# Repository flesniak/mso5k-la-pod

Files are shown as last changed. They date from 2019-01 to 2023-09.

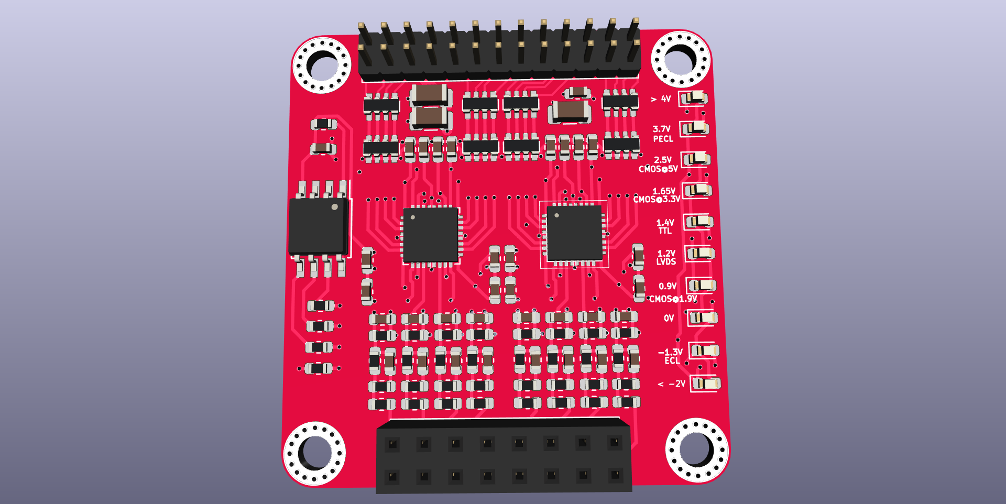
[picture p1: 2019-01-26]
img/lmh7324-8ch-3d.png

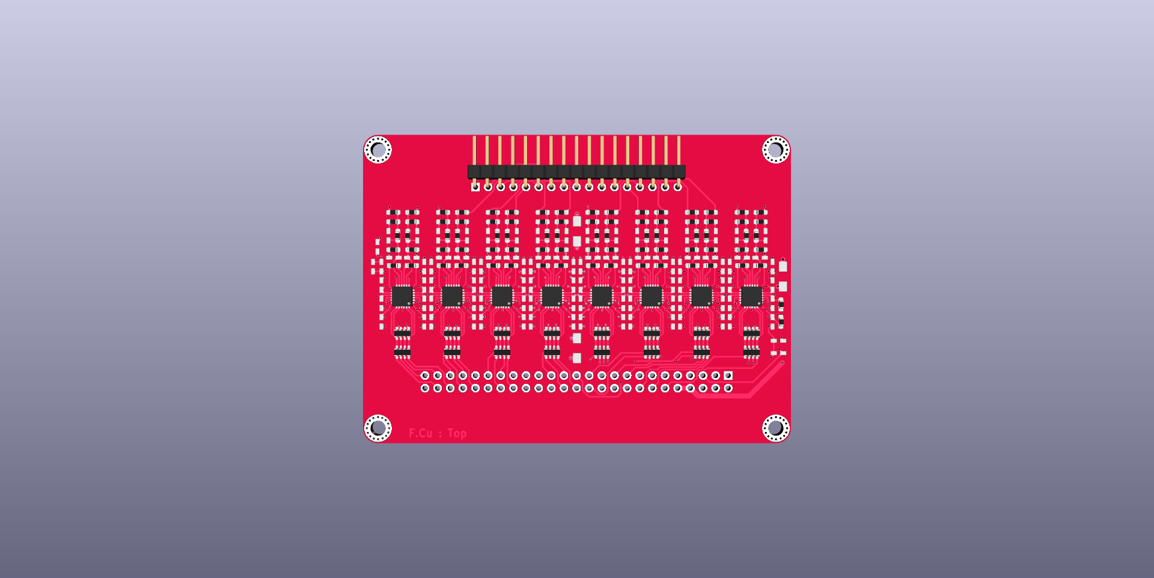
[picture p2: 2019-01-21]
img/pcb-complete-one-sided-4layer-lmh7322.png

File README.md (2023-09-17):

Original version by Flemming Frandsen: https://gitlab.com/dren.dk/mso5k-la-pod

```
MMMMMMMM               MMMMMMMM   SSSSSSSSSSSSSSS      OOOOOOOOO     555555555555555555 kkkkkkkk                            LLLLLLLLLLL                            AAA
M:::::::M             M:::::::M SS:::::::::::::::S   OO:::::::::OO   5::::::::::::::::5 k::::::k                            L:::::::::L                           A:::A
M::::::::M           M::::::::MS:::::SSSSSS::::::S OO:::::::::::::OO 5::::::::::::::::5 k::::::k                            L:::::::::L                          A:::::A
M:::::::::M         M:::::::::MS:::::S     SSSSSSSO:::::::OOO:::::::O5:::::555555555555 k::::::k                            LL:::::::LL                         A:::::::A
M::::::::::M       M::::::::::MS:::::S            O::::::O   O::::::O5:::::5             k:::::k    kkkkkkk                   L:::::L                          A:::::::::A
M:::::::::::M     M:::::::::::MS:::::S            O:::::O     O:::::O5:::::5             k:::::k   k:::::k                    L:::::L                         A:::::A:::::A
M:::::::M::::M   M::::M:::::::M S::::SSSS         O:::::O     O:::::O5:::::5555555555    k:::::k  k:::::k                     L:::::L                        A:::::A A:::::A
M::::::M M::::M M::::M M::::::M  SS::::::SSSSS    O:::::O     O:::::O5:::::::::::::::5   k:::::k k:::::k    ---------------   L:::::L                       A:::::A   A:::::A
M::::::M  M::::M::::M  M::::::M    SSS::::::::SS  O:::::O     O:::::O555555555555:::::5  k::::::k:::::k     -:::::::::::::-   L:::::L                      A:::::A     A:::::A
M::::::M   M:::::::M   M::::::M       SSSSSS::::S O:::::O     O:::::O            5:::::5 k:::::::::::k      ---------------   L:::::L                     A:::::AAAAAAAAA:::::A
M::::::M    M:::::M    M::::::M            S:::::SO:::::O     O:::::O            5:::::5 k:::::::::::k                        L:::::L                    A:::::::::::::::::::::A
M::::::M     MMMMM     M::::::M            S:::::SO::::::O   O::::::O5555555     5:::::5 k::::::k:::::k                       L:::::L         LLLLLL    A:::::AAAAAAAAAAAAA:::::A
M::::::M               M::::::MSSSSSSS     S:::::SO:::::::OOO:::::::O5::::::55555::::::5k::::::k k:::::k                    LL:::::::LLLLLLLLL:::::L   A:::::A             A:::::A
M::::::M               M::::::MS::::::SSSSSS:::::S OO:::::::::::::OO  55:::::::::::::55 k::::::k  k:::::k                   L::::::::::::::::::::::L  A:::::A               A:::::A
M::::::M               M::::::MS:::::::::::::::SS    OO:::::::::OO      55:::::::::55   k::::::k   k:::::k                  L::::::::::::::::::::::L A:::::A                 A:::::A
MMMMMMMM               MMMMMMMM SSSSSSSSSSSSSSS        OOOOOOOOO          555555555     kkkkkkkk    kkkkkkk                 LLLLLLLLLLLLLLLLLLLLLLLLAAAAAAA                   AAAAAAA
```

This is a reimplementation of the Logic Analyzer pod for the Rigol MSO5000 scopes.

The scopes all come with the ability to accept a logic analyzer, all that's needed is a probe, this project is the implementation of the probe.

The schematic and PCB is in kicad 5 format.

# Sub-projects

There are a number of different projects each in its own subdir:

## lmh7324-16ch

* All 16 channels on a single board
* Uses 4x LMH7324 comparators
* Shows threshold voltage of each 8ch bank

## lmh7324-8ch

* 8 channel frontend pod
* On a 4 layer board
* With lmh7324 comparators
* And a simple volt-meter that shows the threshold voltage.

## breakout
* Board for converting the 2x25 2.54 mm pitch connector on the scope to two 2x13 pin 1.27 mm pitch connectors.

## panel-2019-03-20

* Panel produced in march.

## voltmeter

The firmware for the micro controller

# Unfinished experiments

## lmh7322
* 16 channel frontend pod
* Pretty close clone of the original
* One-sided load
* On a 4 layer board
* Direct 2x50 2.54mm ribbon connector to the scope
* Status: Done, except for silkscreen

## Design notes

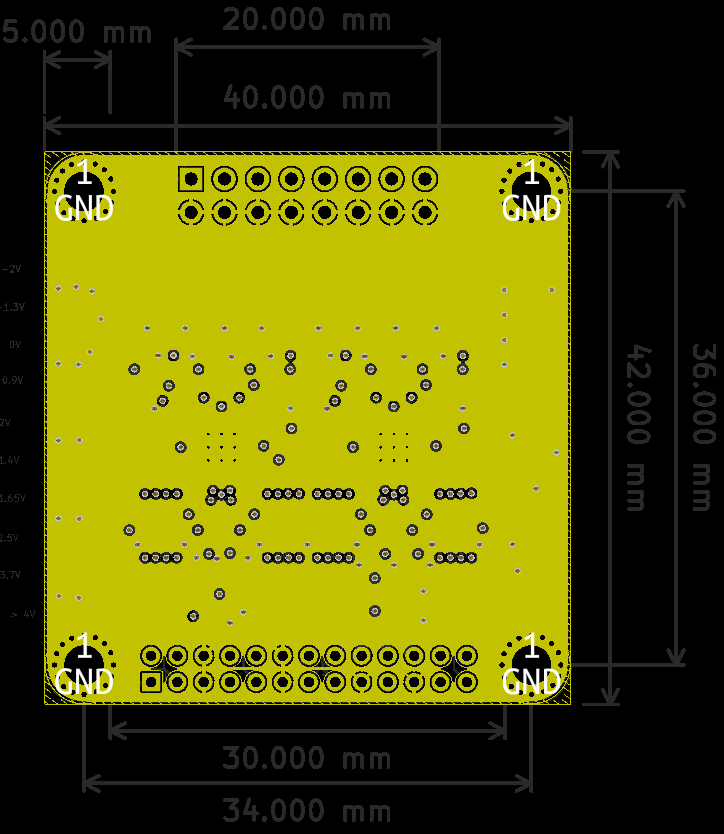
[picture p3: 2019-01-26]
img/lmh7324-8ch-8ch-layer-2-gnd.png

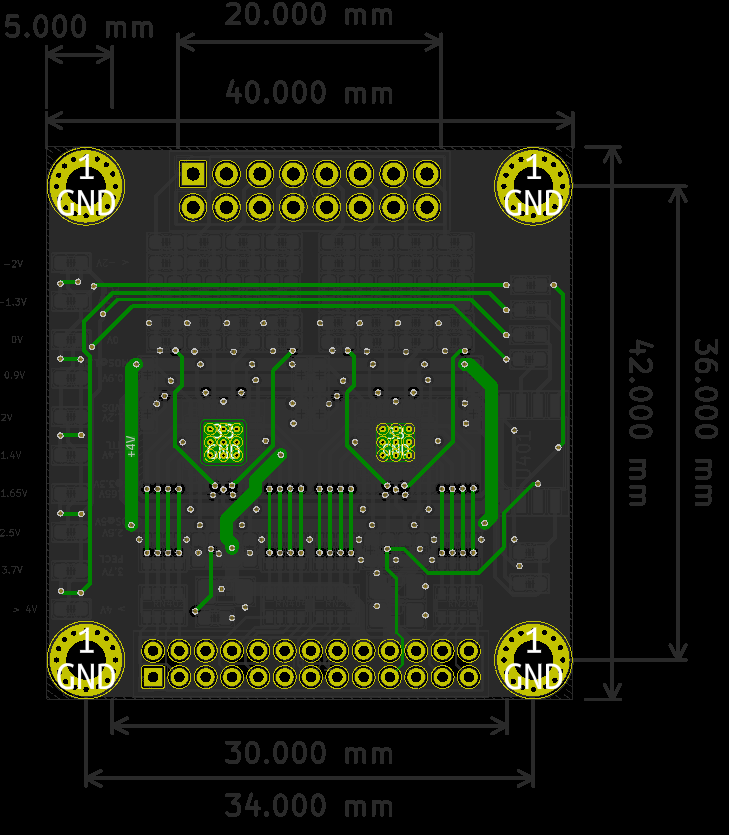
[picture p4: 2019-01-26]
img/lmh7324-8ch-8ch-bottom.png

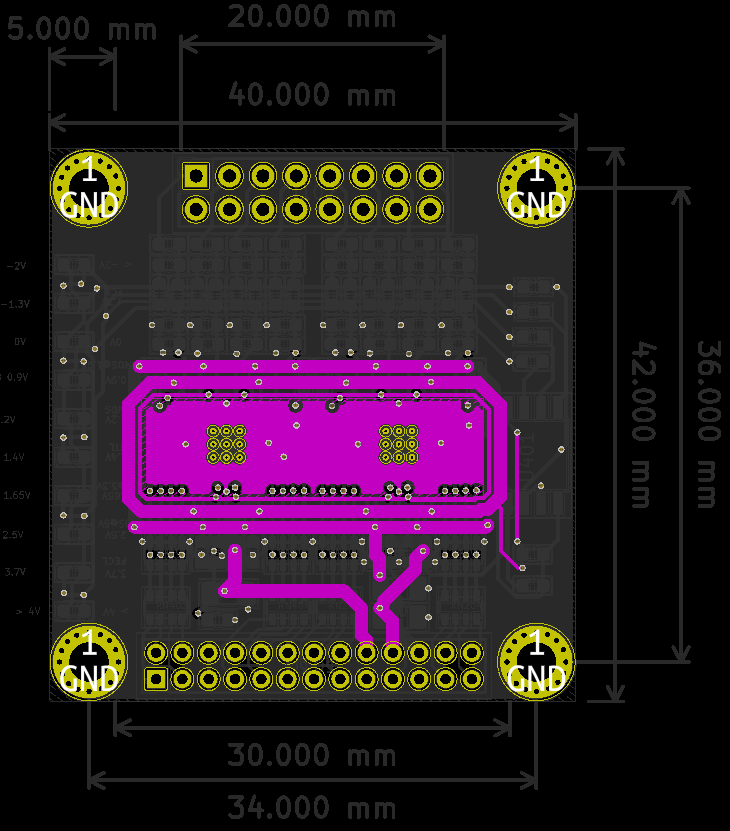
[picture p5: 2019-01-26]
img/lmh7324-8ch-8ch-layer-3-power.png

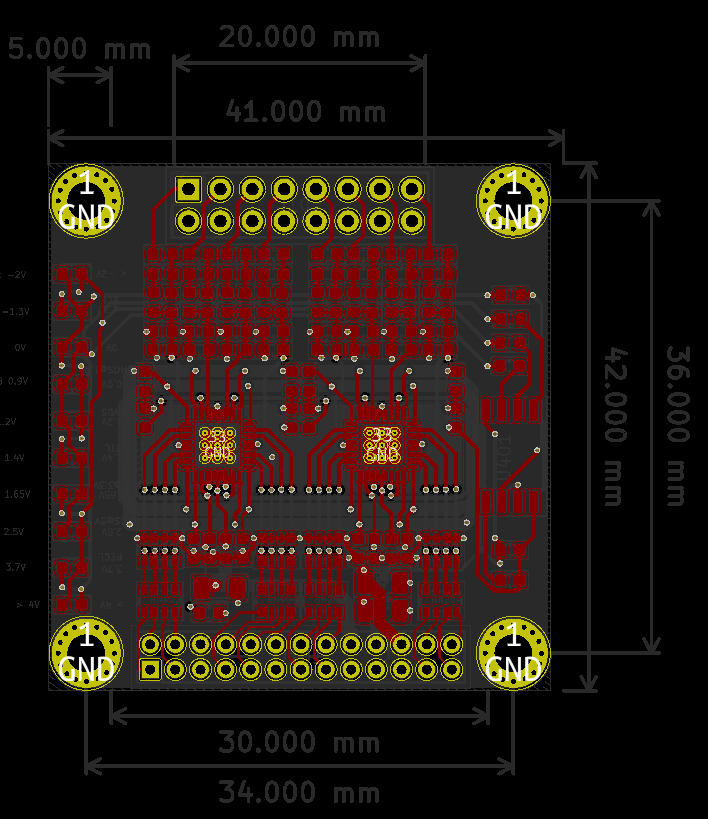
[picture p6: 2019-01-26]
img/lmh7324-8ch-8ch-top.png

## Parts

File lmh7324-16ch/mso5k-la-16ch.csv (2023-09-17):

Source: | /home/fabian/repositories/elektronik/mso5k-la-pod/lmh7324-16ch/mso5k-la-16ch.kicad_sch
Date: | Mo 22 Mai 2023 22:08:21 CEST
Tool: | Eeschema (6.0.11)
Generator: | /usr/share/kicad/plugins/bom_csv_grouped_by_value_with_fp.py
Component Count: | 237
Ref | Qnty | Value | Cmp name | Footprint | Description | Vendor
C1, C2, C3, | 3 | 10uF | C | Capacitor_SMD:C_0805_2012Metric | Unpolarized capacitor
C4, C22, C23, C25, C26, C27, C28, C50, C51, C53, C54, C55, C56, C61, C62, C80, C81, C83, C84, C85, C86, C108, C109, C111, C112, C113, C114, | 27 | 100n | C | Capacitor_SMD:C_0603_1608Metric | Unpolarized capacitor
C5, C6, C7, C8, C9, C10, C11, C12, C15, C18, C21, C24, C33, C34, C35, C36, C37, C38, C39, C40, C43, C46, C49, C52, C63, C64, C65, C66, C67, C68, C69, C70, C71, C74, C75, C76, C91, C92, C93, C94, C95, C96, C97, C98, C99, C102, C103, C104, | 48 | 10n | C | Capacitor_SMD:C_0402_1005Metric | Unpolarized capacitor
C13, C14, C29, C30, C41, C42, C57, C58, C72, C73, C87, C88, C100, C101, C115, C116, | 16 | 3.3p | C | Capacitor_SMD:C_0603_1608Metric | Unpolarized capacitor
C16, C17, C31, C32, C44, C45, C59, C60, C77, C78, C89, C90, C105, C106, C117, C118, | 16 | 27p | C | Capacitor_SMD:C_0603_1608Metric | Unpolarized capacitor
C19, C20, C47, C48, C79, C82, C107, C110, | 8 | 10n | C | Capacitor_SMD:C_0603_1608Metric | Unpolarized capacitor
D1, D11, | 2 | > 4V | LED | LED_SMD:LED_0603_1608Metric | Light emitting diode
D2, D12, | 2 | PECL 3.7V | LED | LED_SMD:LED_0603_1608Metric | Light emitting diode
D3, D13, | 2 | CMOS 5 2.5V | LED | LED_SMD:LED_0603_1608Metric | Light emitting diode
D4, D14, | 2 | CMOS 3.3 1.65V | LED | LED_SMD:LED_0603_1608Metric | Light emitting diode
D5, D15, | 2 | TTL 1.4V | LED | LED_SMD:LED_0603_1608Metric | Light emitting diode
D6, D16, | 2 | LVDS 1.2V | LED | LED_SMD:LED_0603_1608Metric | Light emitting diode
D7, D17, | 2 | CMOS 1.8 0.9V | LED | LED_SMD:LED_0603_1608Metric | Light emitting diode
D8, D18, | 2 | 0V | LED | LED_SMD:LED_0603_1608Metric | Light emitting diode
D9, D19, | 2 | ECL -1.3V | LED | LED_SMD:LED_0603_1608Metric | Light emitting diode
D10, D20, | 2 | < -2V | LED | LED_SMD:LED_0603_1608Metric | Light emitting diode
H1, H2, H3, H4, | 4 | MountingHole_Pad | MountingHole_Pad | MountingHole:MountingHole_3.2mm_M3_Pad_Via | Mounting Hole with connection
J1, | 1 | scope | Conn_02x25_Odd_Even | Connector_IDC:IDC-Header_2x25_P2.54mm_Vertical | Generic connector, double row, 02x25, odd/even pin numbering scheme (row 1 odd numbers, row 2 even numbers), script generated (kicad-library-utils/schlib/autogen/connector/)
J2, J7, | 2 | in | Conn_02x08_Odd_Even | Connector_PinSocket_2.54mm:PinSocket_2x08_P2.54mm_Vertical | Generic connector, double row, 02x08, odd/even pin numbering scheme (row 1 odd numbers, row 2 even numbers), script generated (kicad-library-utils/schlib/autogen/connector/)
J8, | 1 | Conn_02x03_Odd_Even | Conn_02x03_Odd_Even | Connector_PinSocket_2.54mm:PinSocket_2x03_P2.54mm_Vertical | Generic connector, double row, 02x03, odd/even pin numbering scheme (row 1 odd numbers, row 2 even numbers), script generated (kicad-library-utils/schlib/autogen/connector/)
J9, | 1 | Conn_01x04_Female | Conn_01x04_Female | Connector_PinHeader_2.54mm:PinHeader_1x04_P2.54mm_Vertical | Generic connector, single row, 01x04, script generated (kicad-library-utils/schlib/autogen/connector/)
R1, R2, R9, R10, R17, R18, R25, R26, R38, R39, R46, R47, R54, R55, R62, R63, | 16 | 300 | R | Resistor_SMD:R_0603_1608Metric | Resistor
R3, R4, R11, R12, R19, R20, R27, R28, R40, R41, R48, R49, R56, R57, R64, R65, | 16 | 497 | R | Resistor_SMD:R_0603_1608Metric | Resistor
R5, R6, R13, R14, R21, R22, R29, R30, R42, R43, R50, R51, R58, R59, R66, R67, | 16 | 90k8 | R | Resistor_SMD:R_0603_1608Metric | Resistor
R7, R8, R15, R16, R23, R24, R31, R32, R44, R45, R52, R53, R60, R61, R68, R69, | 16 | 10k | R | Resistor_SMD:R_0603_1608Metric | Resistor
R33, R34, R35, R36, R37, | 5 | 220 | R | Resistor_SMD:R_0603_1608Metric | Resistor
RN1, RN3, RN5, RN7, RN9, RN11, RN13, RN15, | 8 | 200 | R_Pack04 | Resistor_SMD:R_Array_Convex_4x0603 | 4 resistor network, parallel topology
RN2, RN4, RN6, RN8, RN10, RN12, RN14, RN16, | 8 | 49R9 | R_Pack04 | Resistor_SMD:R_Array_Convex_4x0603 | 4 resistor network, parallel topology
U1, | 1 | ATtiny44A-SS | ATtiny44A-SS | Package_SO:SOIC-14_3.9x8.7mm_P1.27mm | 20MHz, 4kB Flash, 256B SRAM, 256B EEPROM, debugWIRE, SOIC-14
U2, U3, U4, U5, | 4 | LMH7324 | LMH7324 | Package_DFN_QFN:WQFN-32-1EP_5x5mm_P0.5mm_EP3.1x3.1mm | Quad 700 ps High Speed Comparator with RSPECL Outputs, WQFN-32

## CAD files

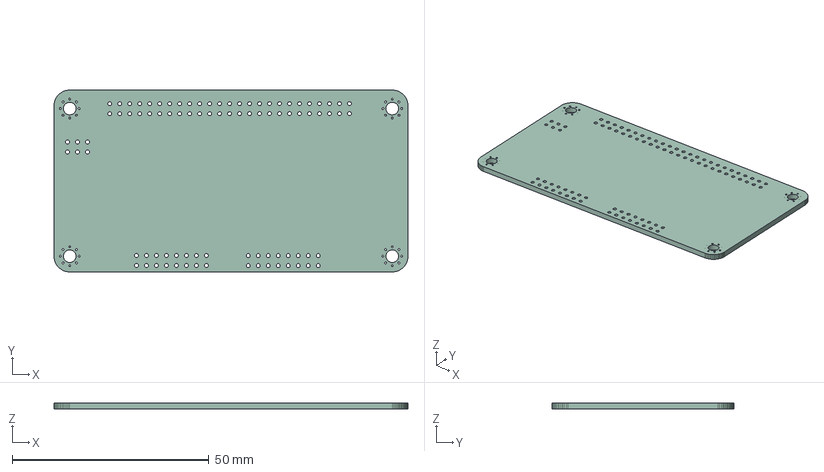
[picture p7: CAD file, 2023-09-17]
lmh7324-16ch/mso5k-la-16ch.step
90.0 x 46.2 x 1.58 mm

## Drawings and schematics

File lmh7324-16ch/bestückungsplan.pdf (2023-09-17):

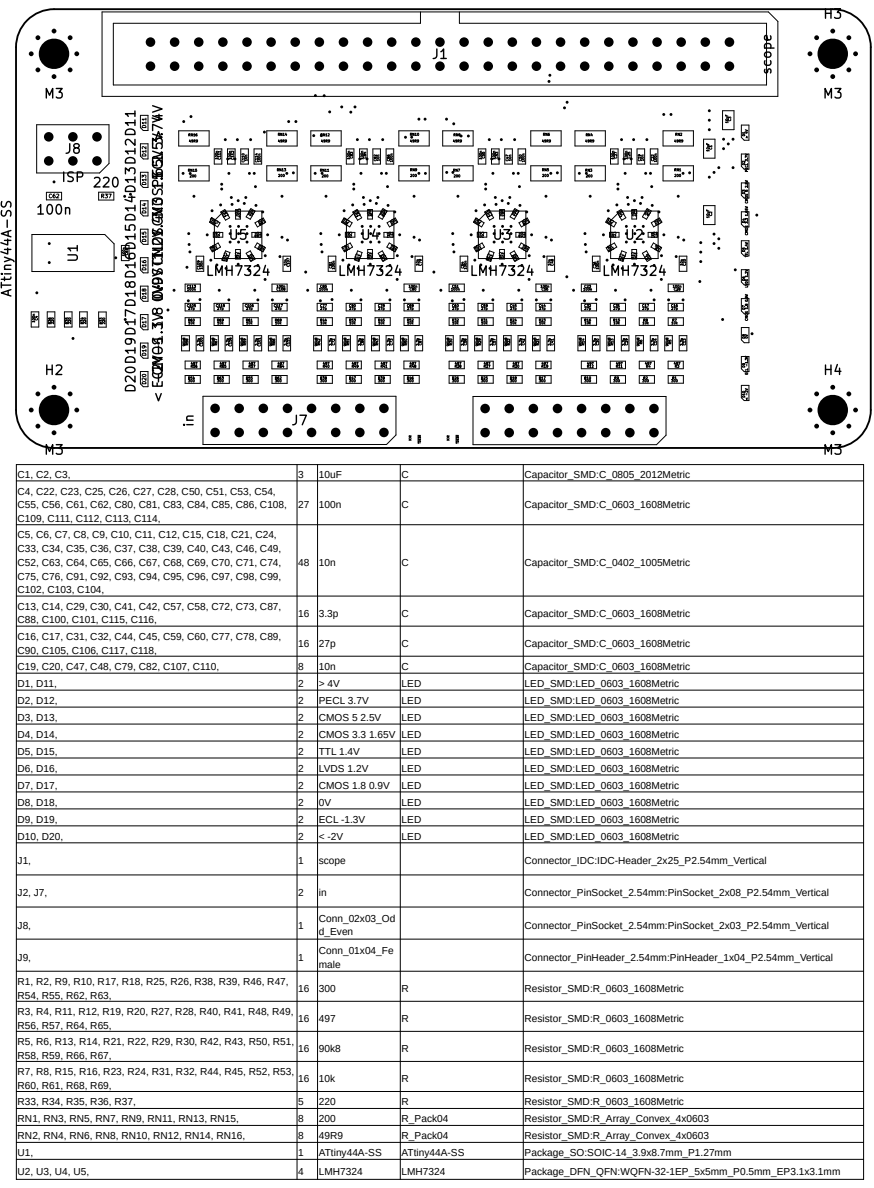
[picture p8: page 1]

C1, C2, C3, | 3 | 10uF | C | Capacitor_SMD:C_0805_2012Metric
C4, C22, C23, C25, C26, C27, C28, C50, C51, C53, C54, C55, C56, C61, C62, C80, C81, C83, C84, C85, C86, C108, C109, C111, C112, C113, C114, | 27 | 100n | C | Capacitor_SMD:C_0603_1608Metric

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

C19, C20, C47, C48, C79, C82, C107, C110, | 8 | 10n | C | Capacitor_SMD:C_0603_1608Metric
D1, D11, | 2 | > 4V | LED | LED_SMD:LED_0603_1608Metric
D2, D12, | 2 | PECL 3.7V | LED | LED_SMD:LED_0603_1608Metric
D3, D13, | 2 | CMOS 5 2.5V | LED | LED_SMD:LED_0603_1608Metric
D4, D14, | 2 | CMOS 3.3 1.65V | LED | LED_SMD:LED_0603_1608Metric
D5, D15, | 2 | TTL 1.4V | LED | LED_SMD:LED_0603_1608Metric
D6, D16, | 2 | LVDS 1.2V | LED | LED_SMD:LED_0603_1608Metric
D7, D17, | 2 | CMOS 1.8 0.9V | LED | LED_SMD:LED_0603_1608Metric
D8, D18, | 2 | 0V | LED | LED_SMD:LED_0603_1608Metric
D9, D19, | 2 | ECL -1.3V | LED | LED_SMD:LED_0603_1608Metric
D10, D20, | 2 | < -2V | LED | LED_SMD:LED_0603_1608Metric

J1, | 1 | scope | | Connector_IDC:IDC-Header_2x25_P2.54mm_Vertical

J2, J7, | 2 | in | | Connector_PinSocket_2.54mm:PinSocket_2x08_P2.54mm_Vertical

J8, | 1 | Conn_02x03_Od d_Even | | Connector_PinSocket_2.54mm:PinSocket_2x03_P2.54mm_Vertical

J9, | 1 | Conn_01x04_Fe male | | Connector_PinHeader_2.54mm:PinHeader_1x04_P2.54mm_Vertical

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

R33, R34, R35, R36, R37, | 5 | 220 | R | Resistor_SMD:R_0603_1608Metric
RN1, RN3, RN5, RN7, RN9, RN11, RN13, RN15, | 8 | 200 | R_Pack04 | Resistor_SMD:R_Array_Convex_4x0603
RN2, RN4, RN6, RN8, RN10, RN12, RN14, RN16, | 8 | 49R9 | R_Pack04 | Resistor_SMD:R_Array_Convex_4x0603
U1, | 1 | ATtiny44A-SS | ATtiny44A-SS | Package_SO:SOIC-14_3.9x8.7mm_P1.27mm
U2, U3, U4, U5, | 4 | LMH7324 | LMH7324 | Package_DFN_QFN:WQFN-32-1EP_5x5mm_P0.5mm_EP3.1x3.1mm

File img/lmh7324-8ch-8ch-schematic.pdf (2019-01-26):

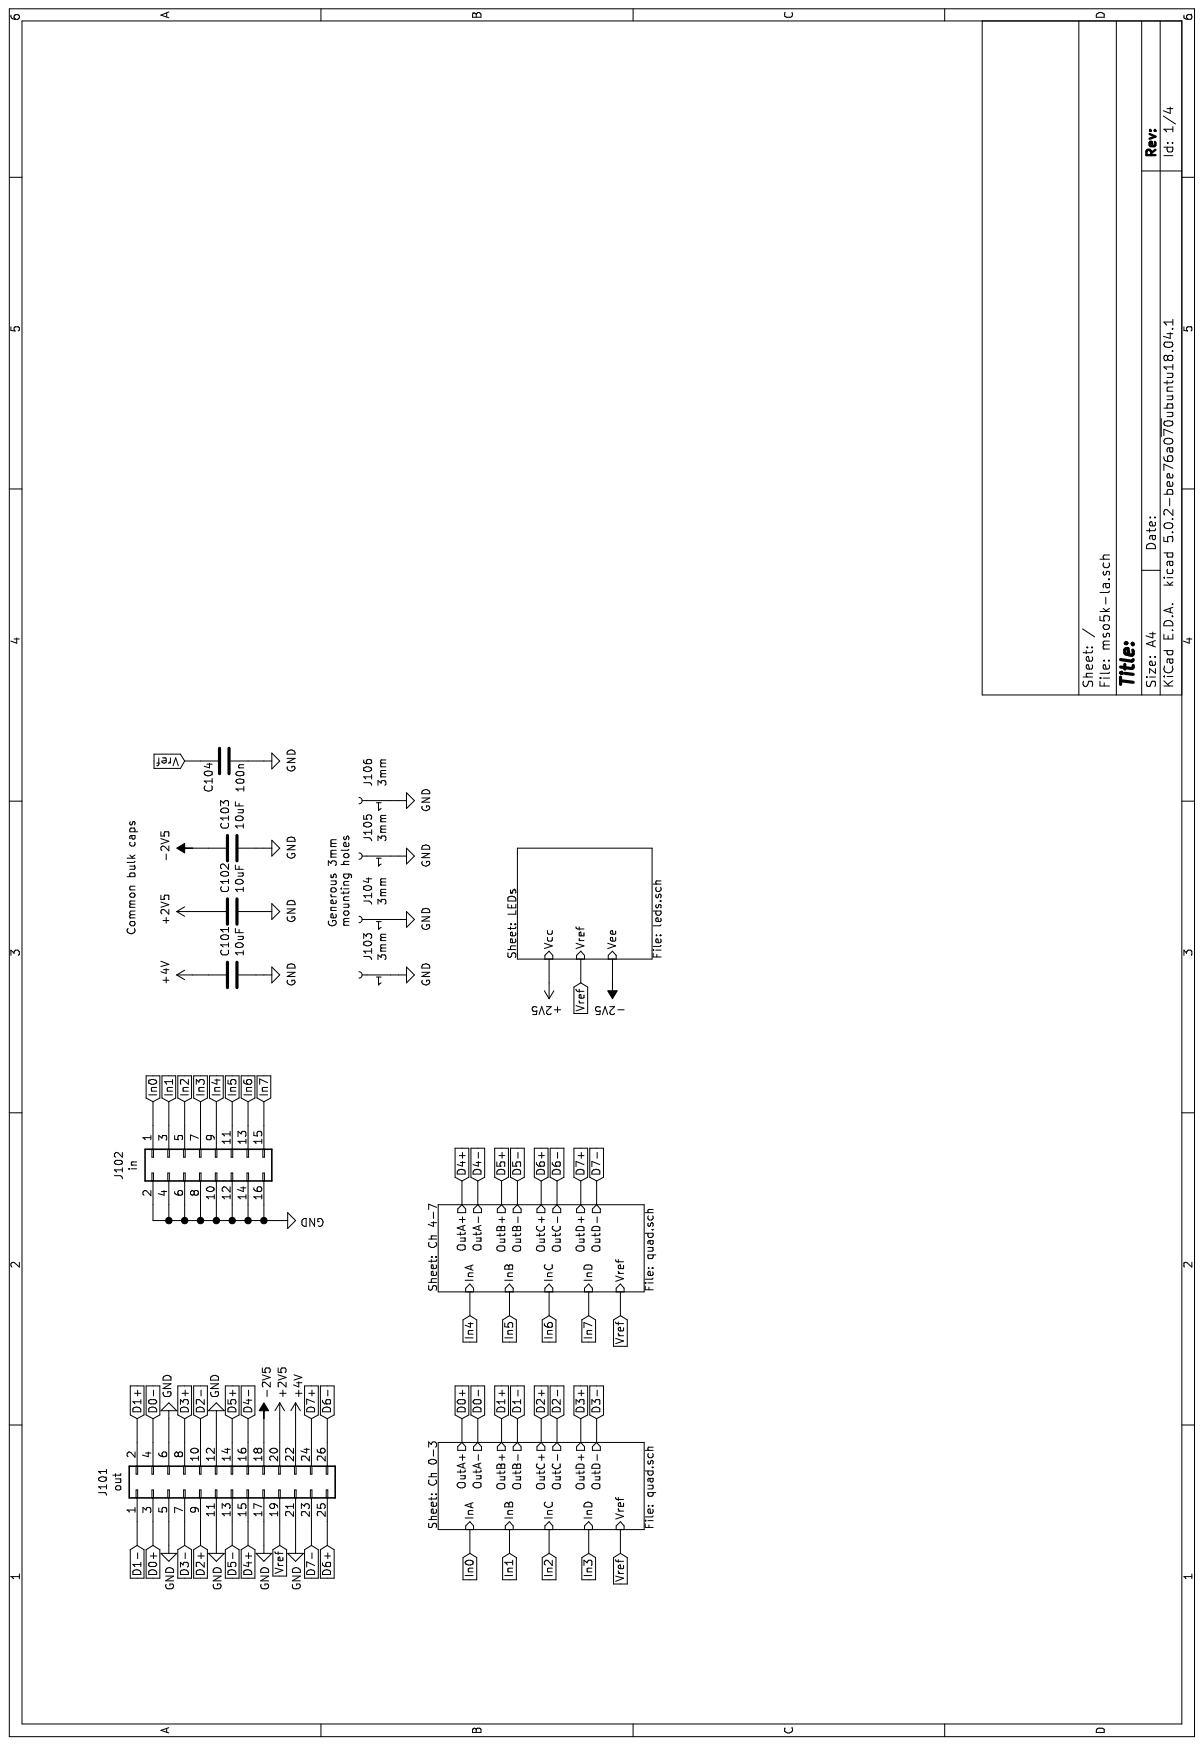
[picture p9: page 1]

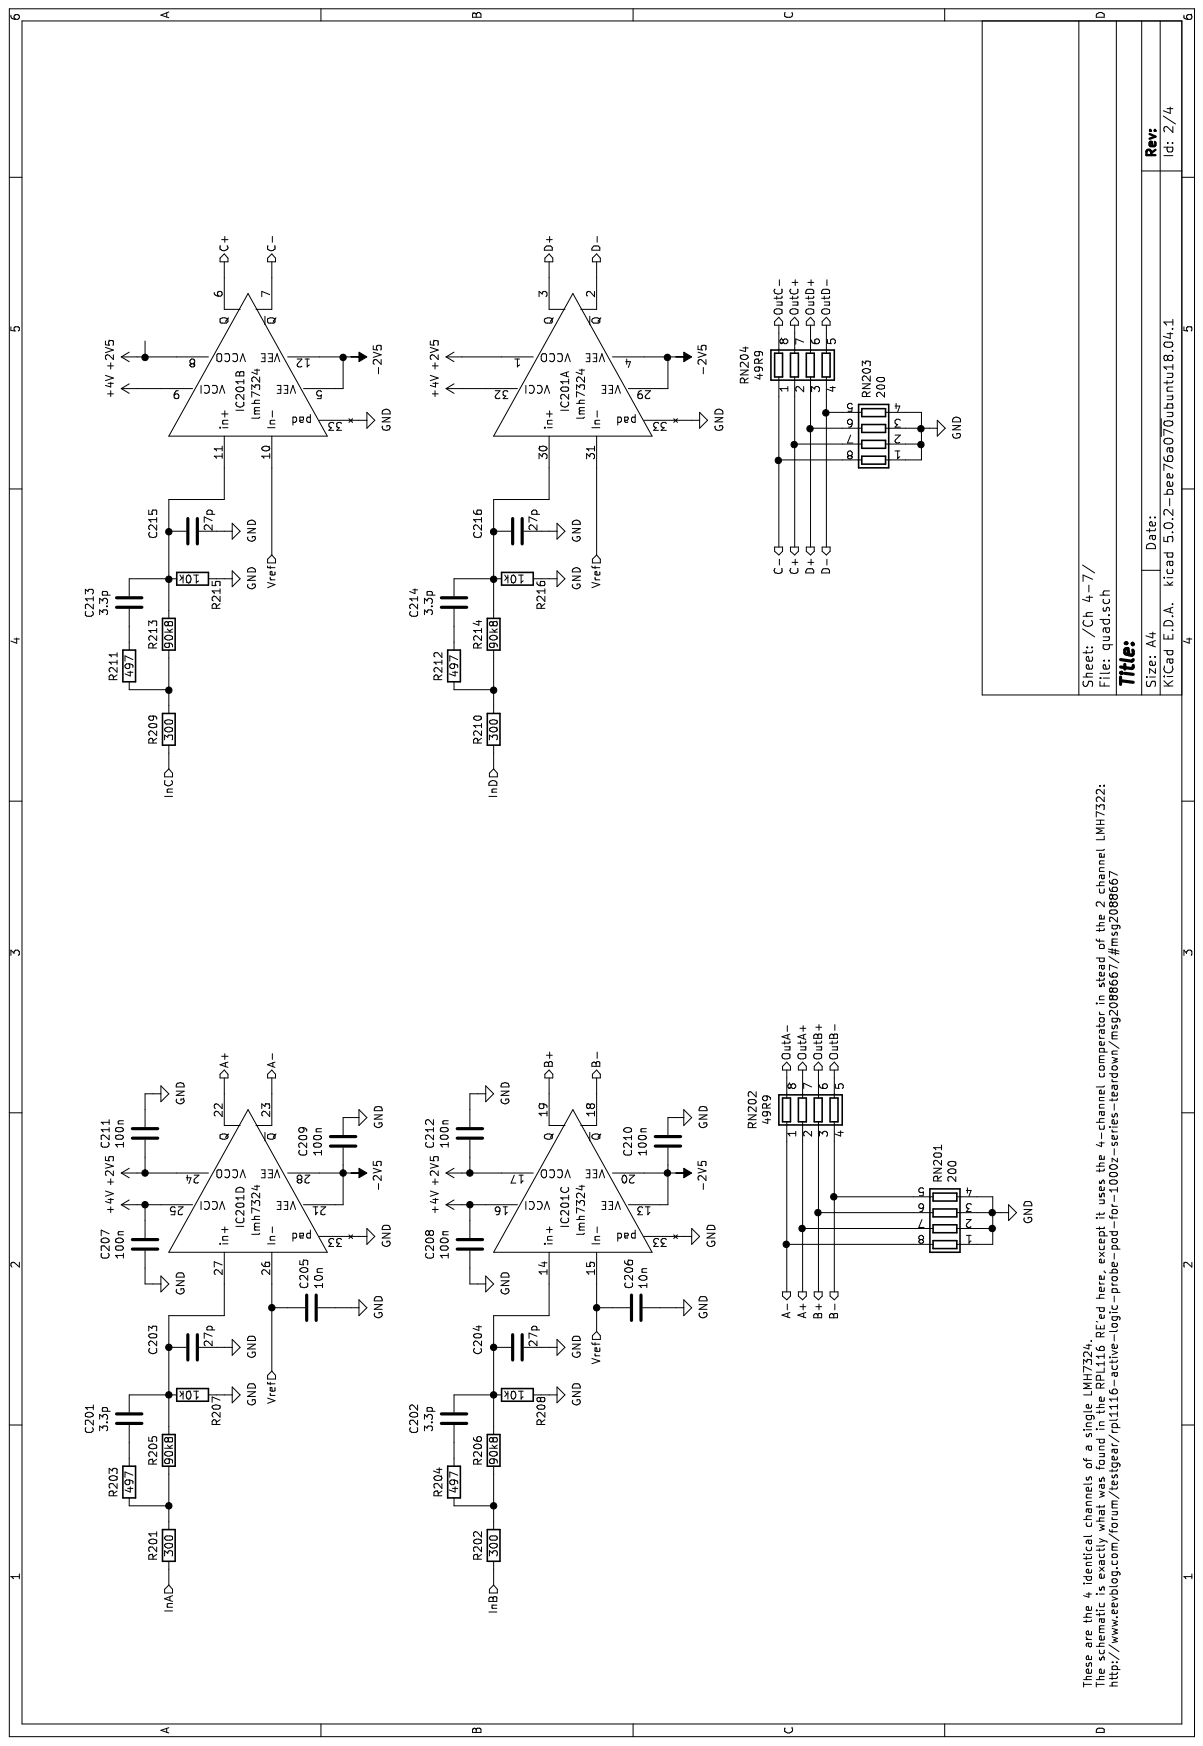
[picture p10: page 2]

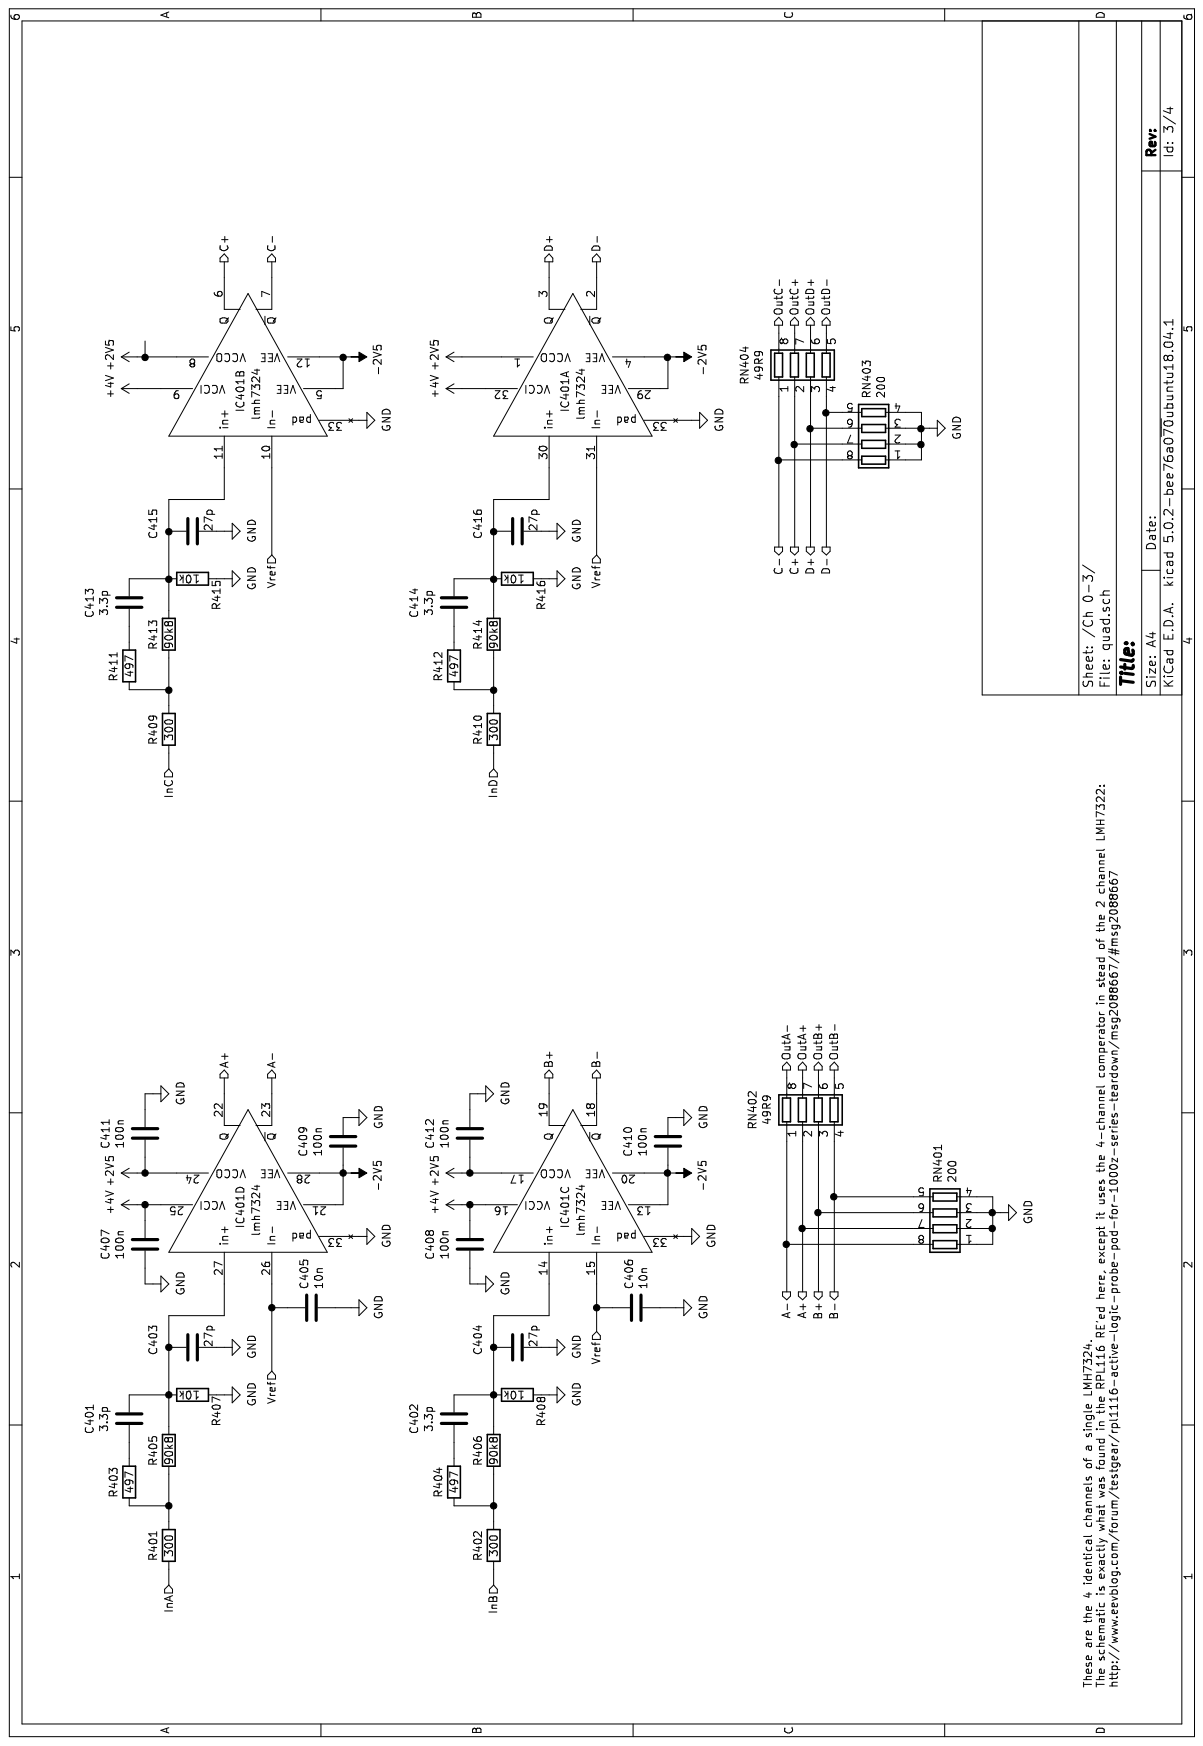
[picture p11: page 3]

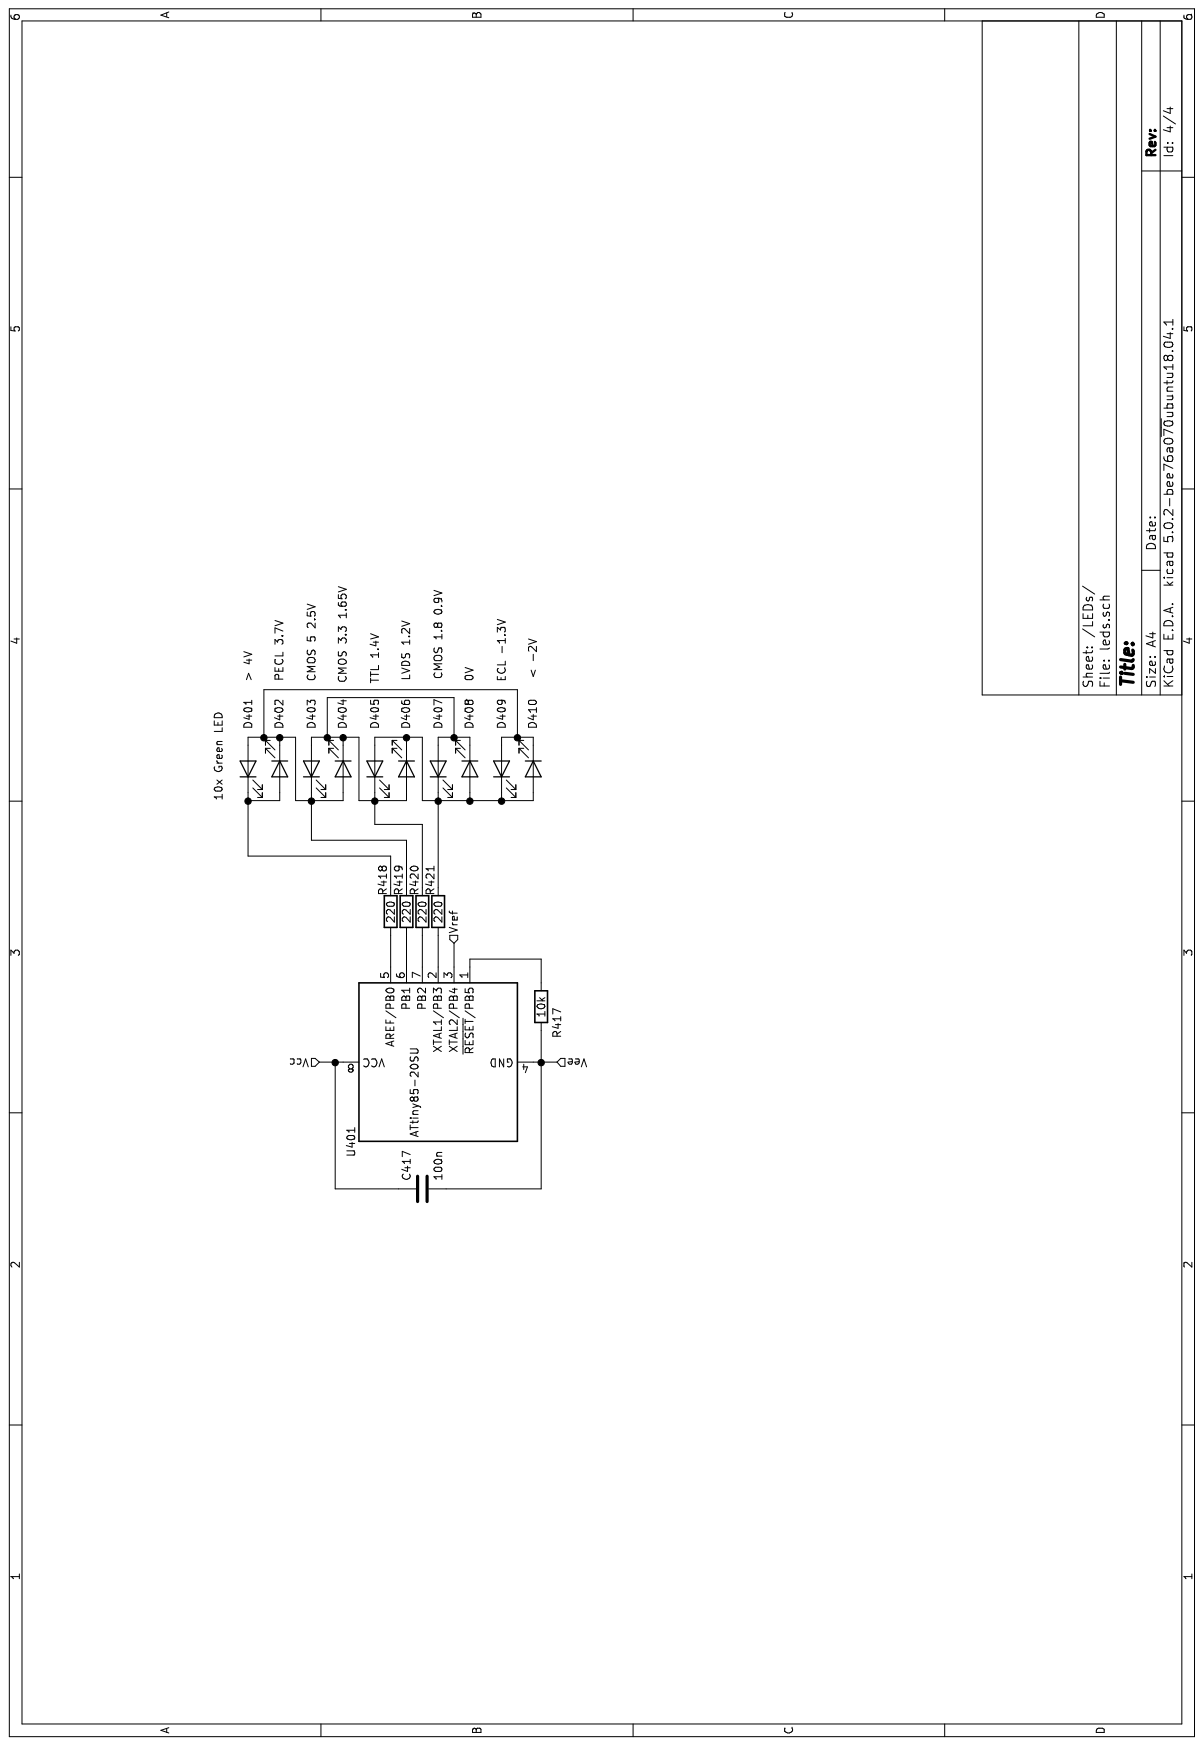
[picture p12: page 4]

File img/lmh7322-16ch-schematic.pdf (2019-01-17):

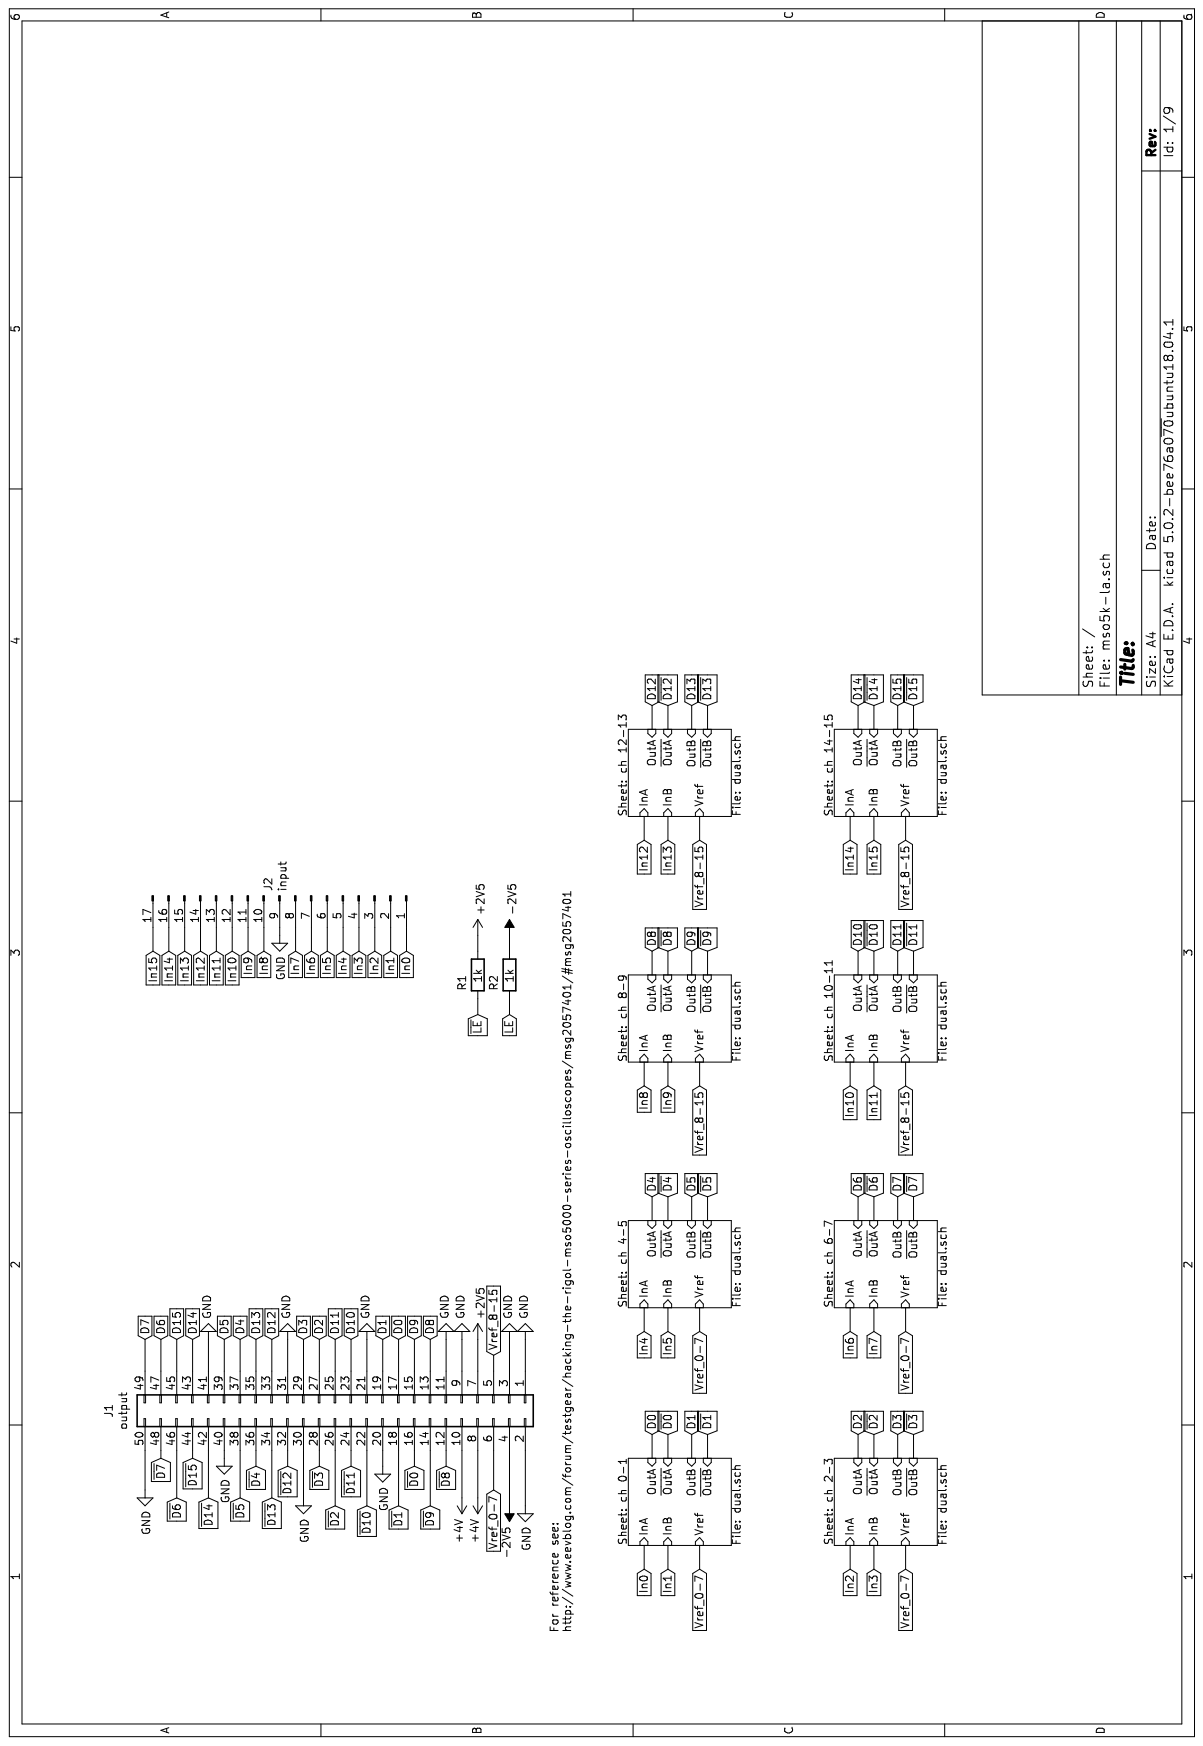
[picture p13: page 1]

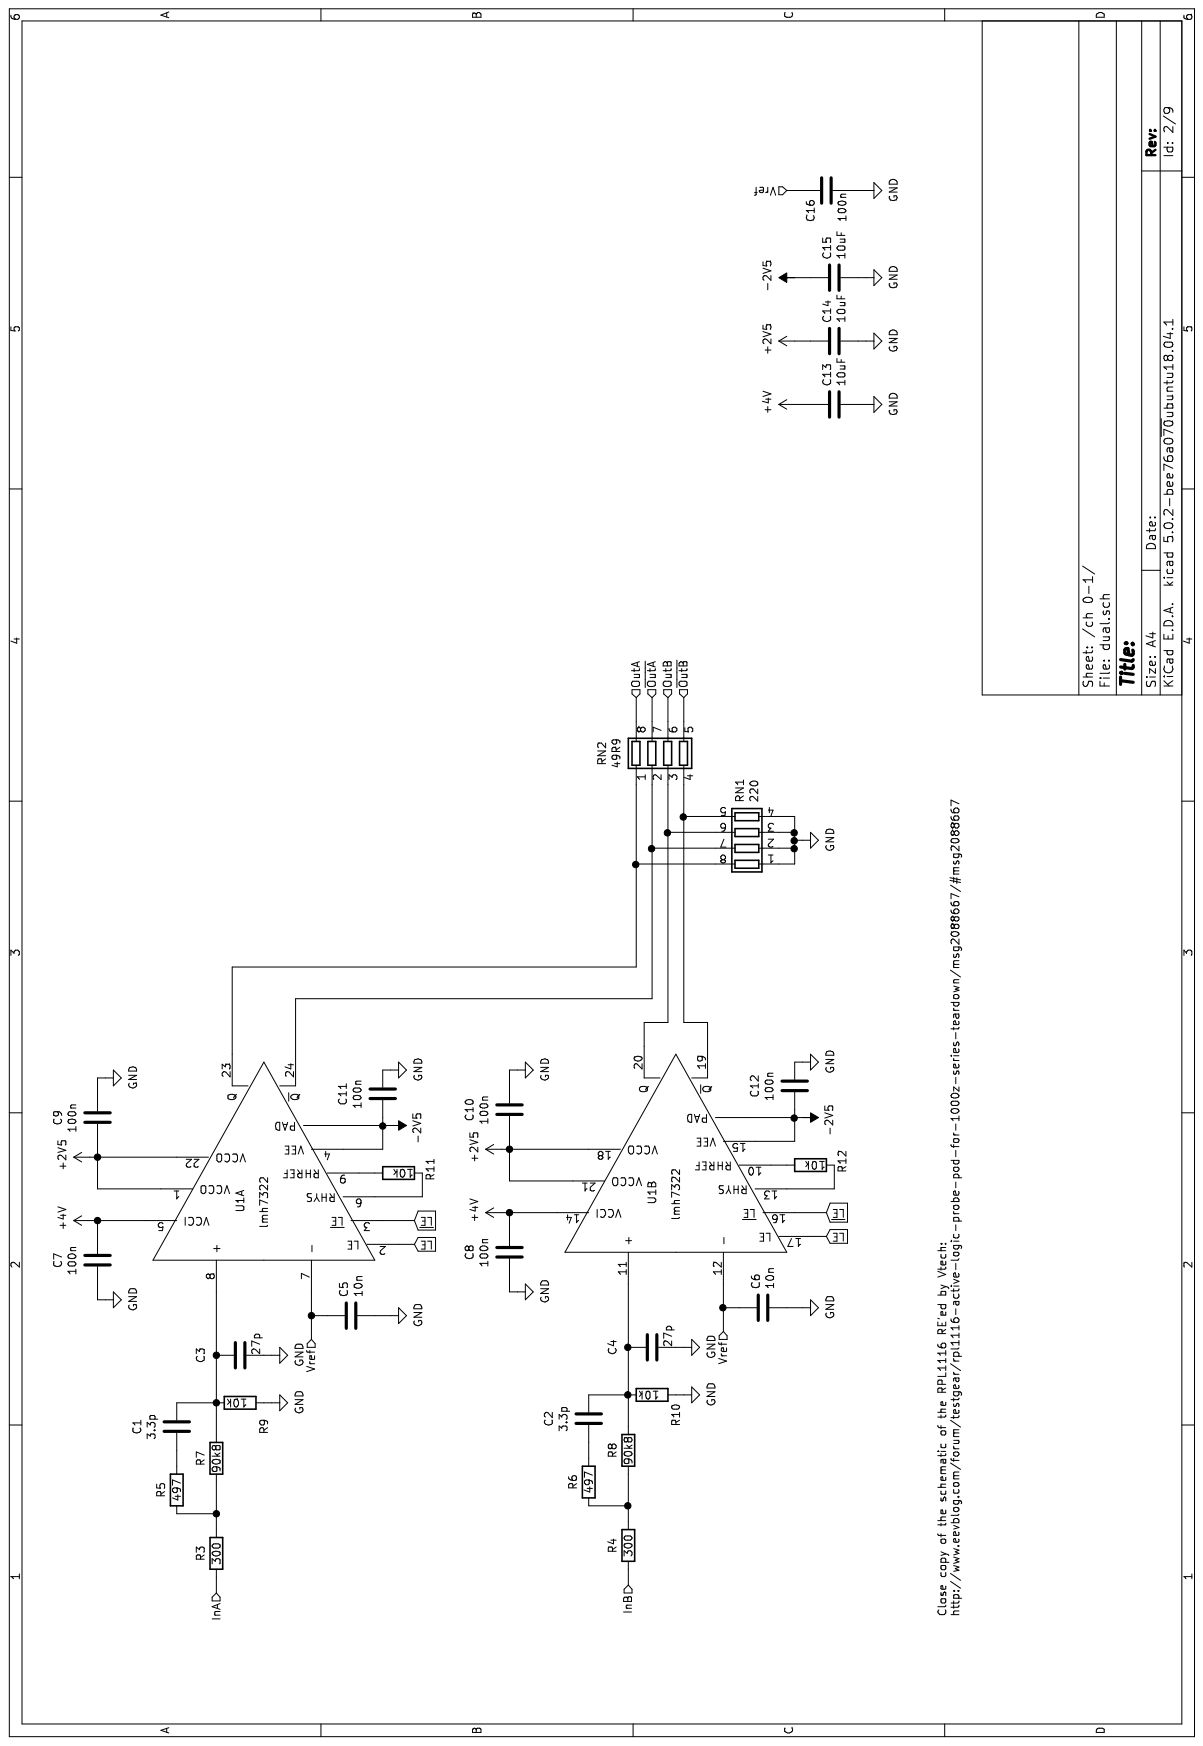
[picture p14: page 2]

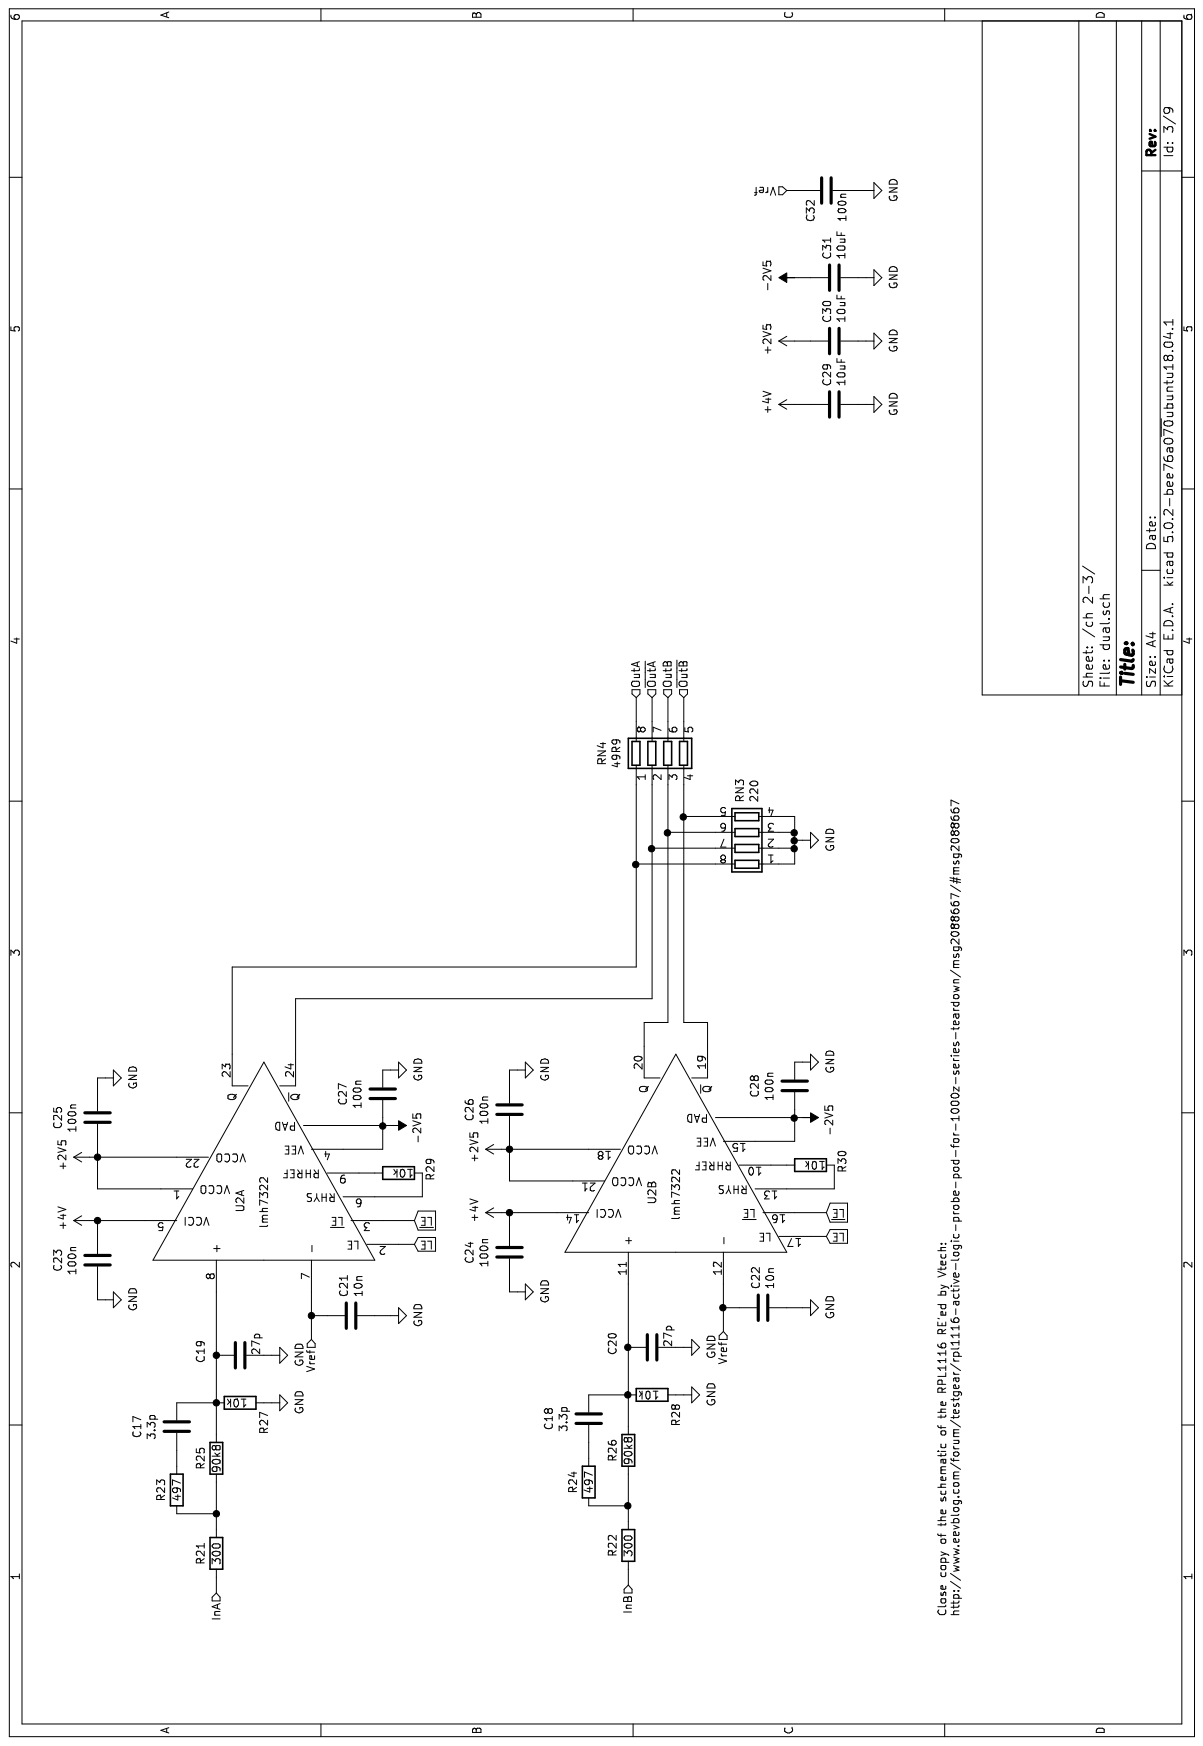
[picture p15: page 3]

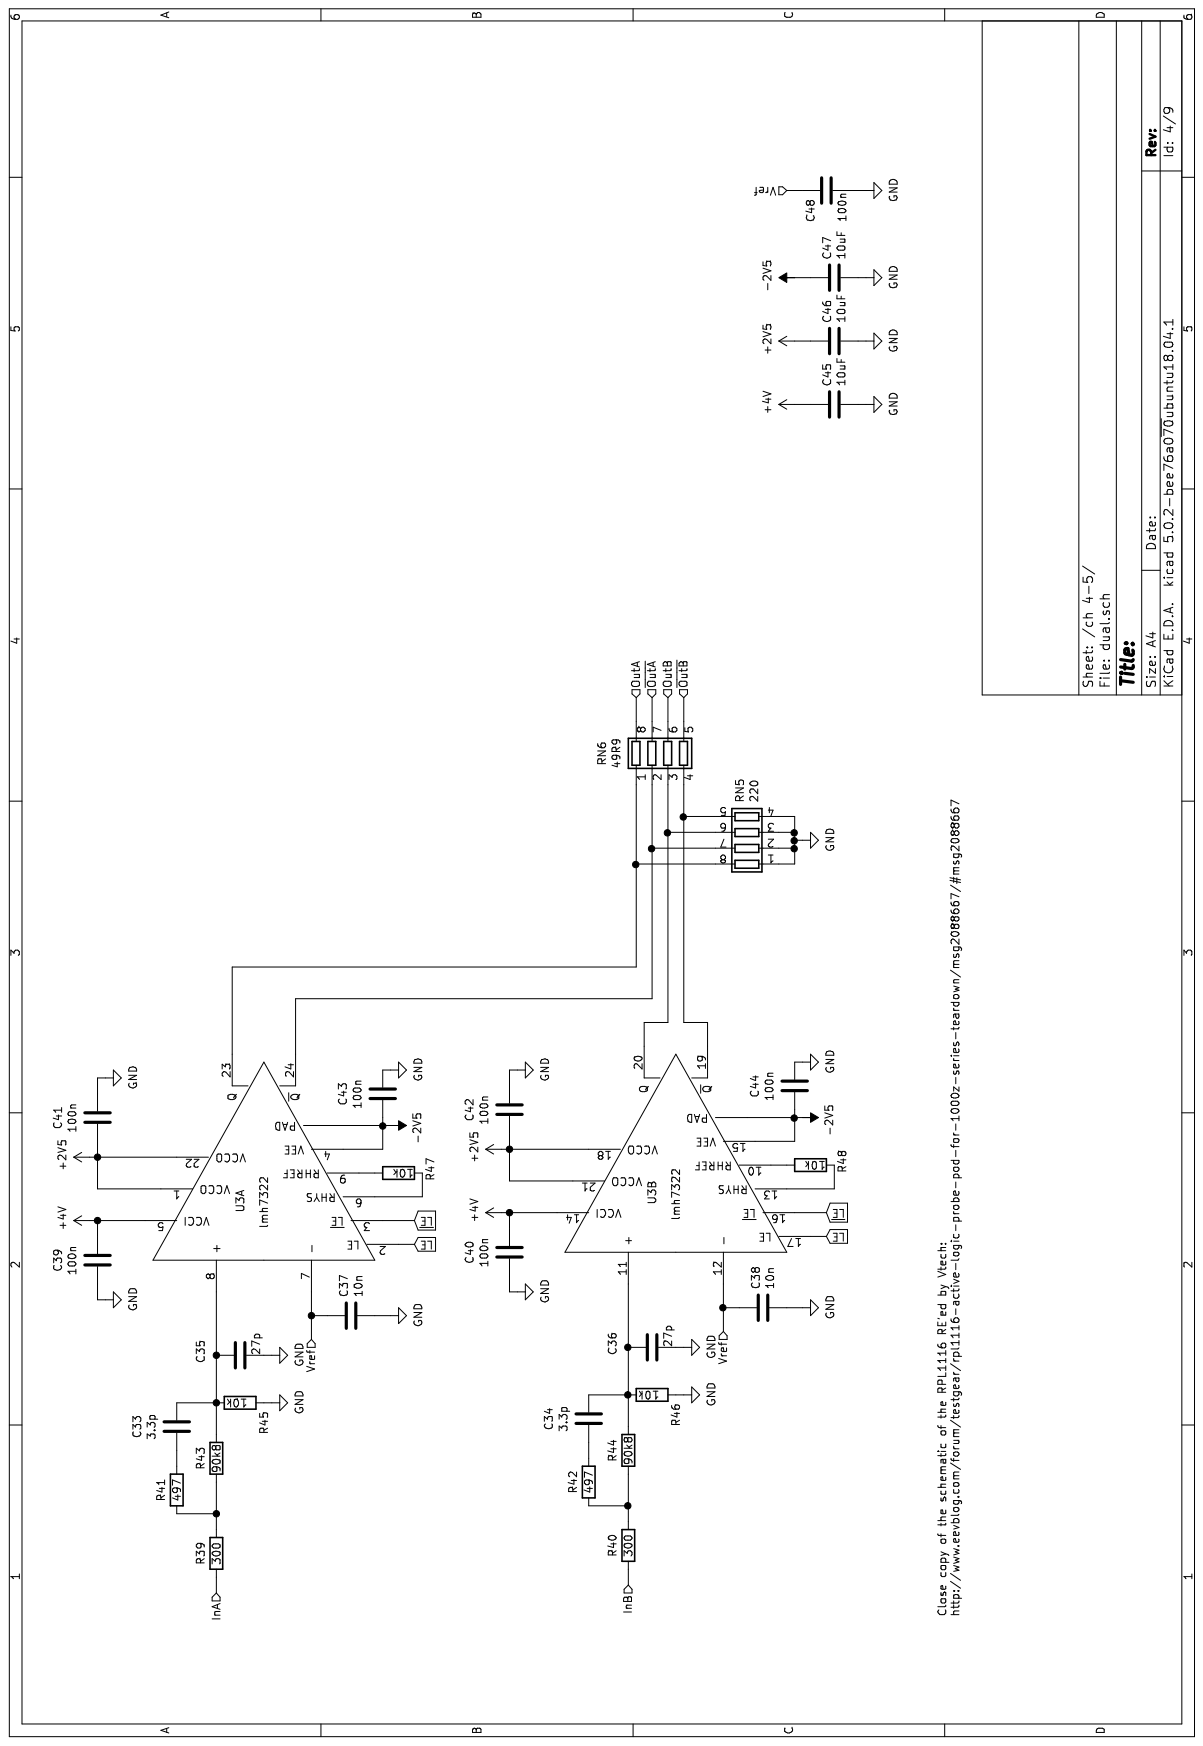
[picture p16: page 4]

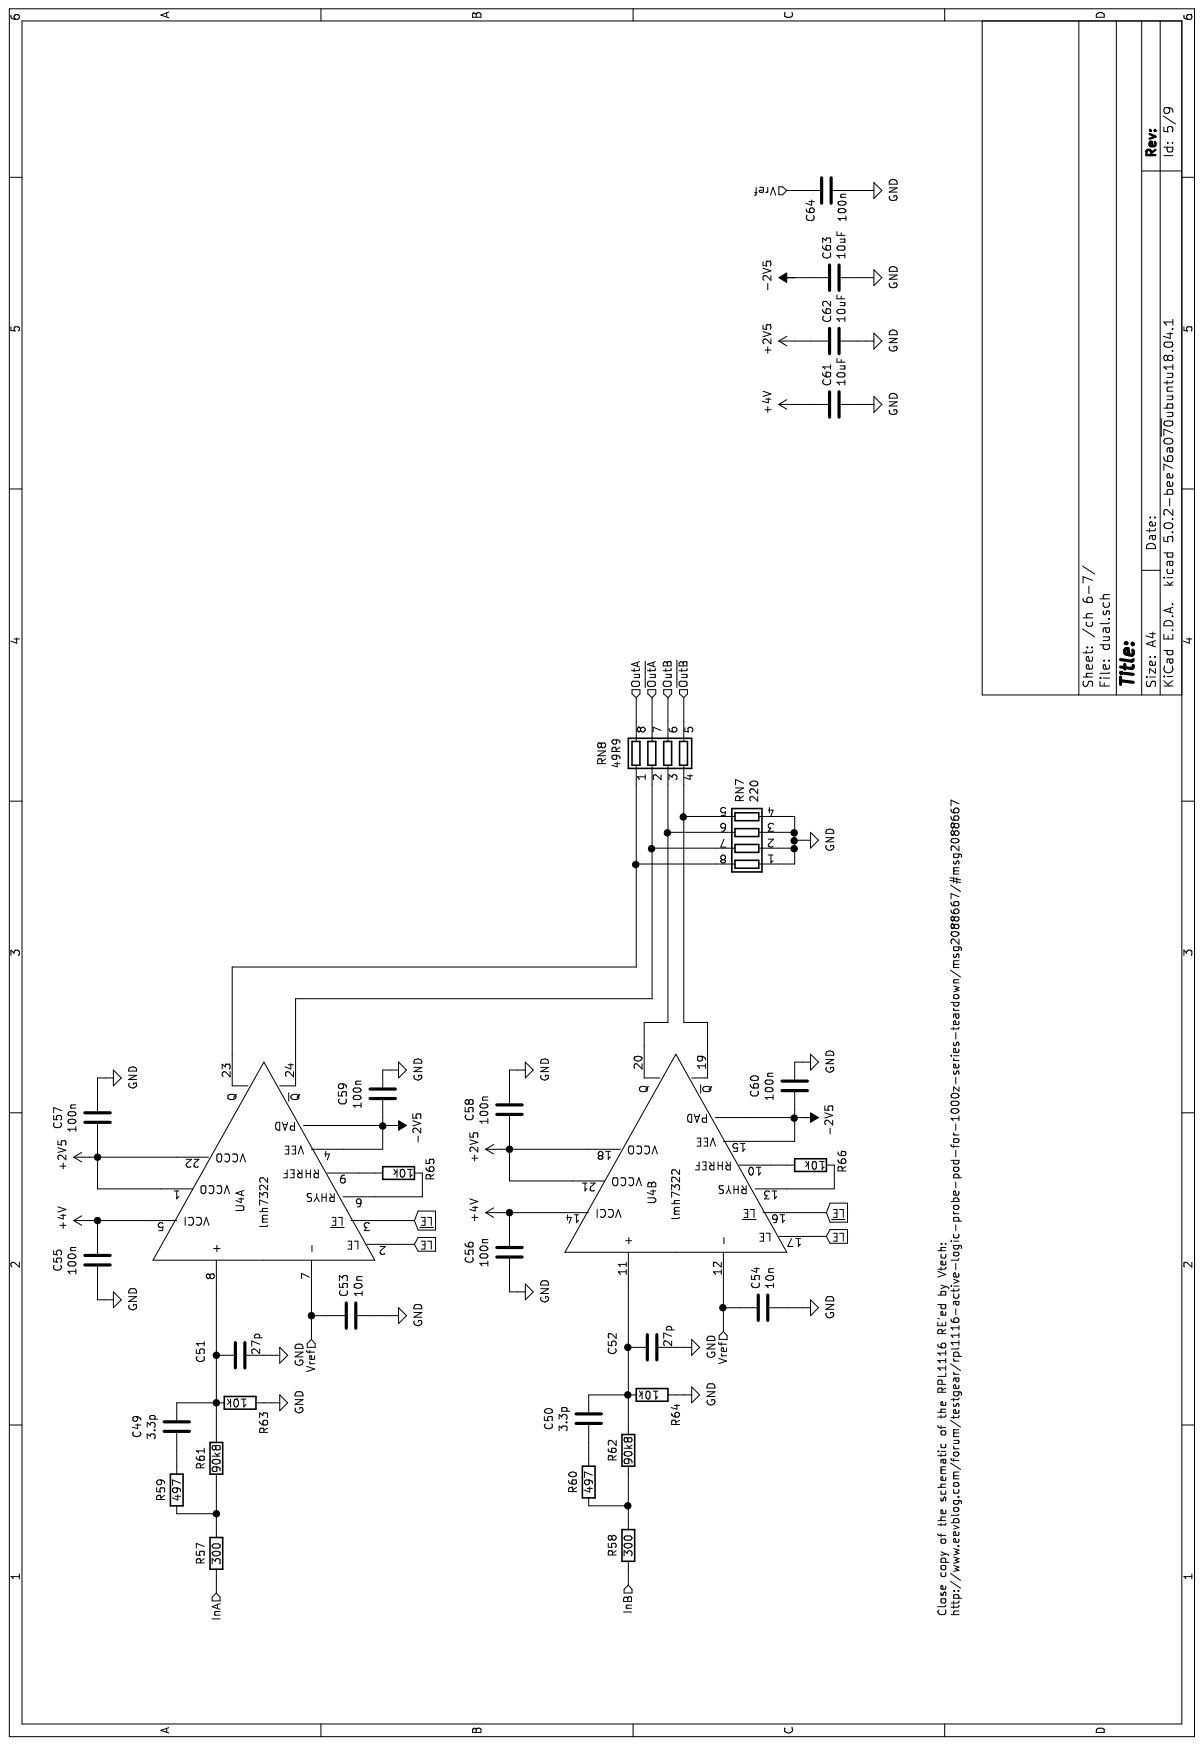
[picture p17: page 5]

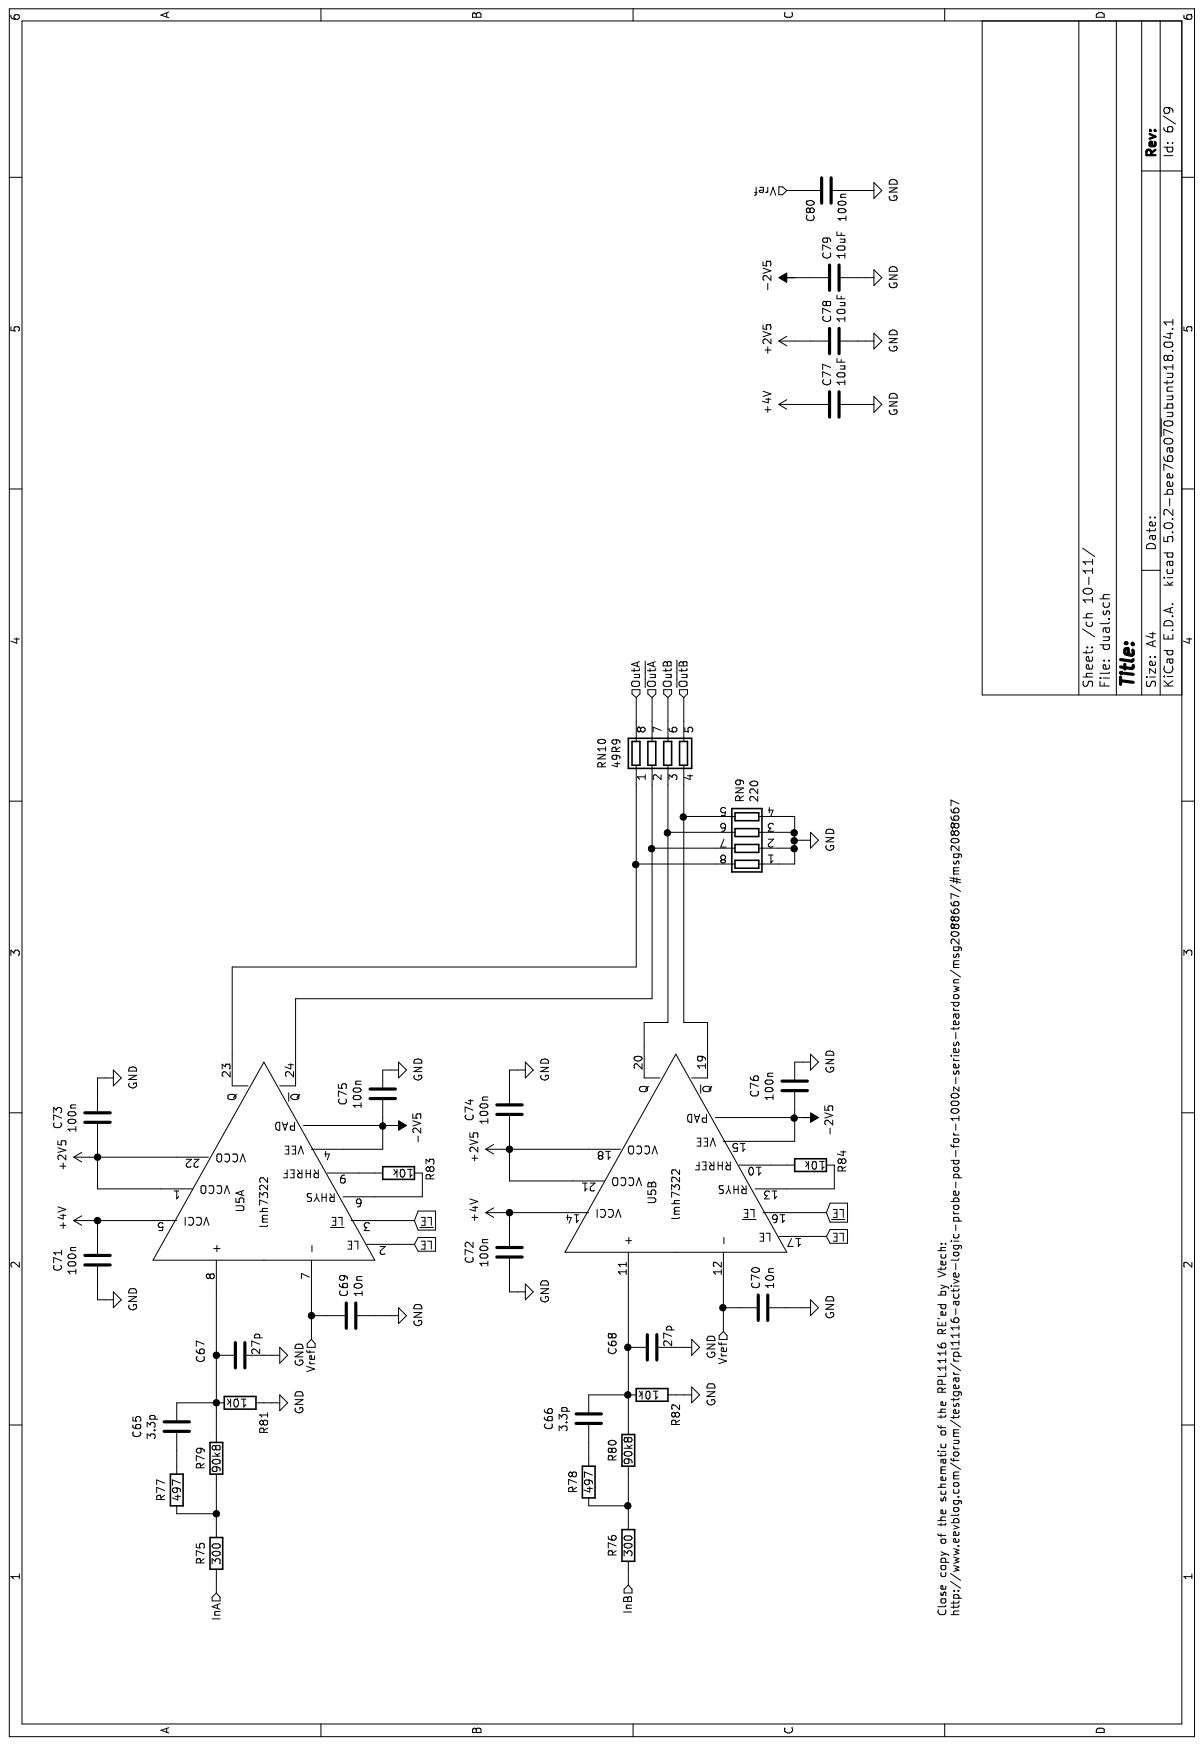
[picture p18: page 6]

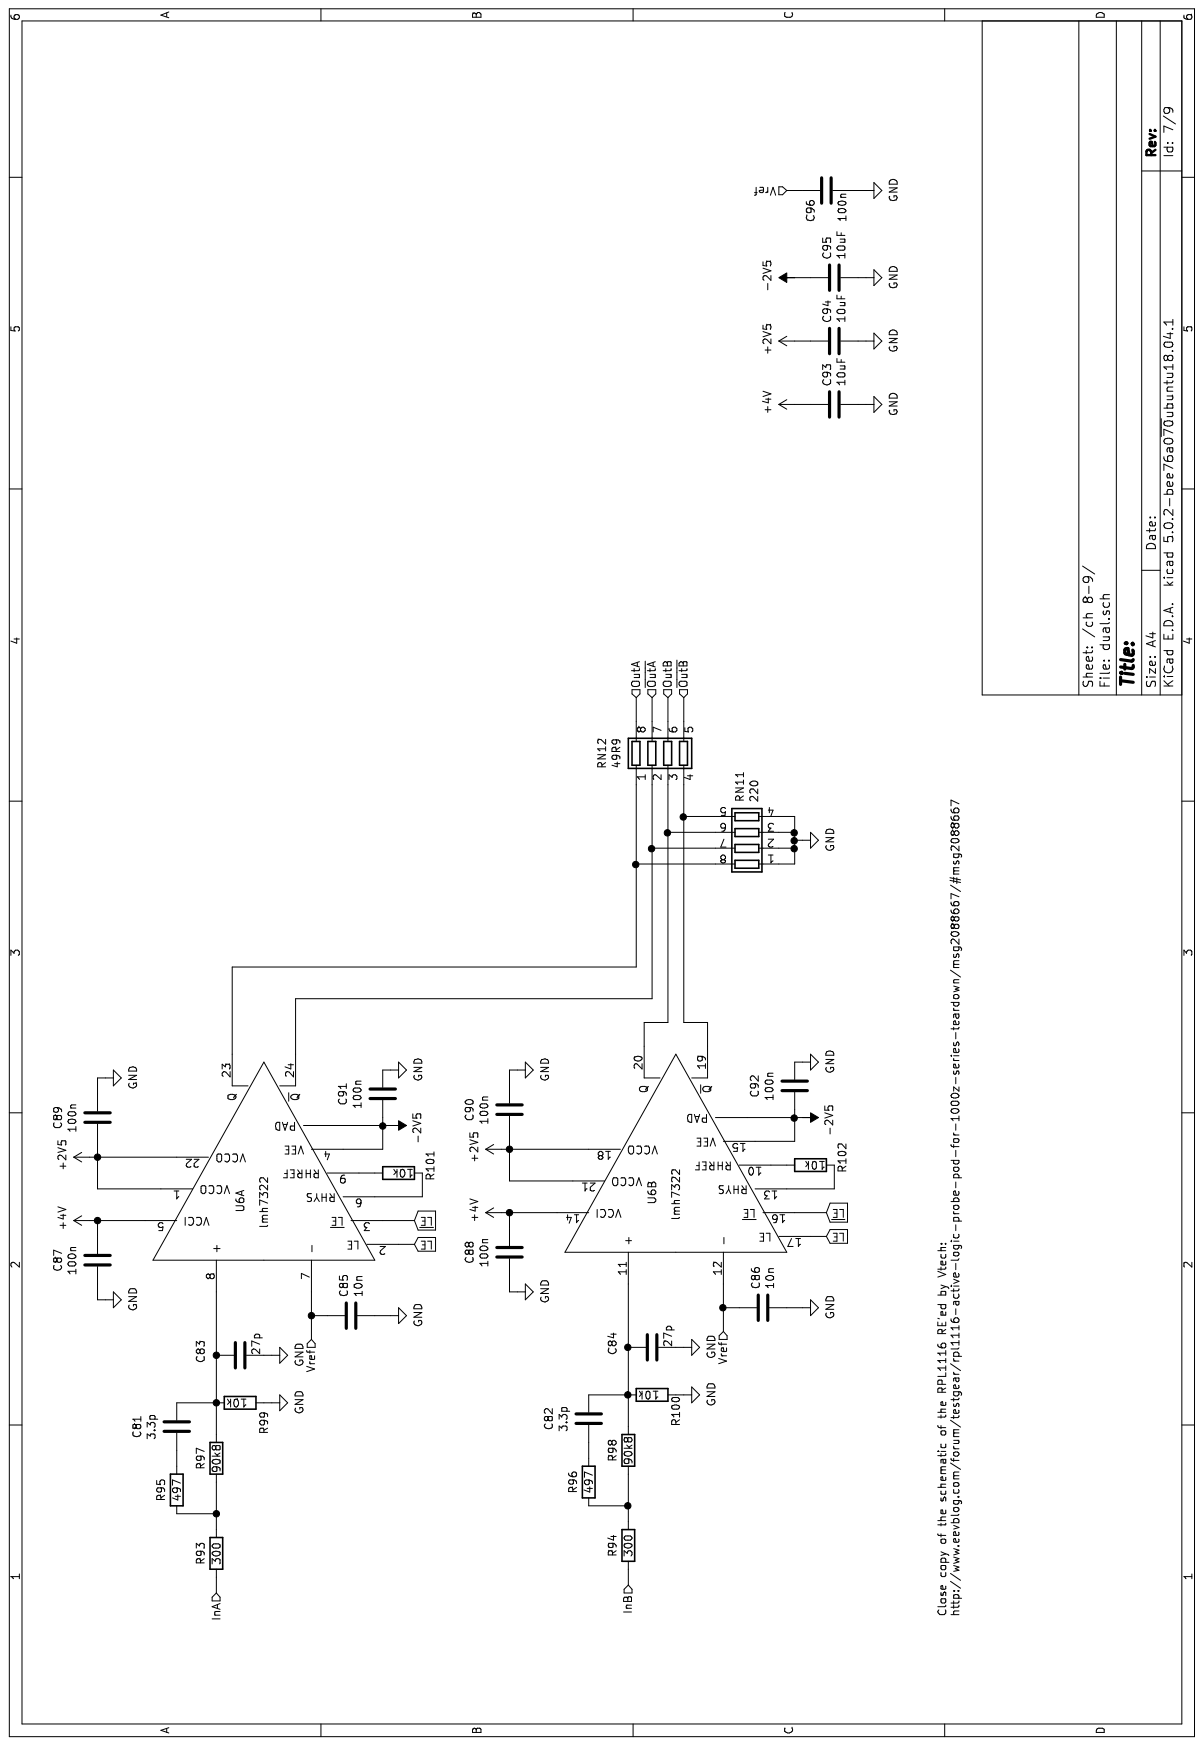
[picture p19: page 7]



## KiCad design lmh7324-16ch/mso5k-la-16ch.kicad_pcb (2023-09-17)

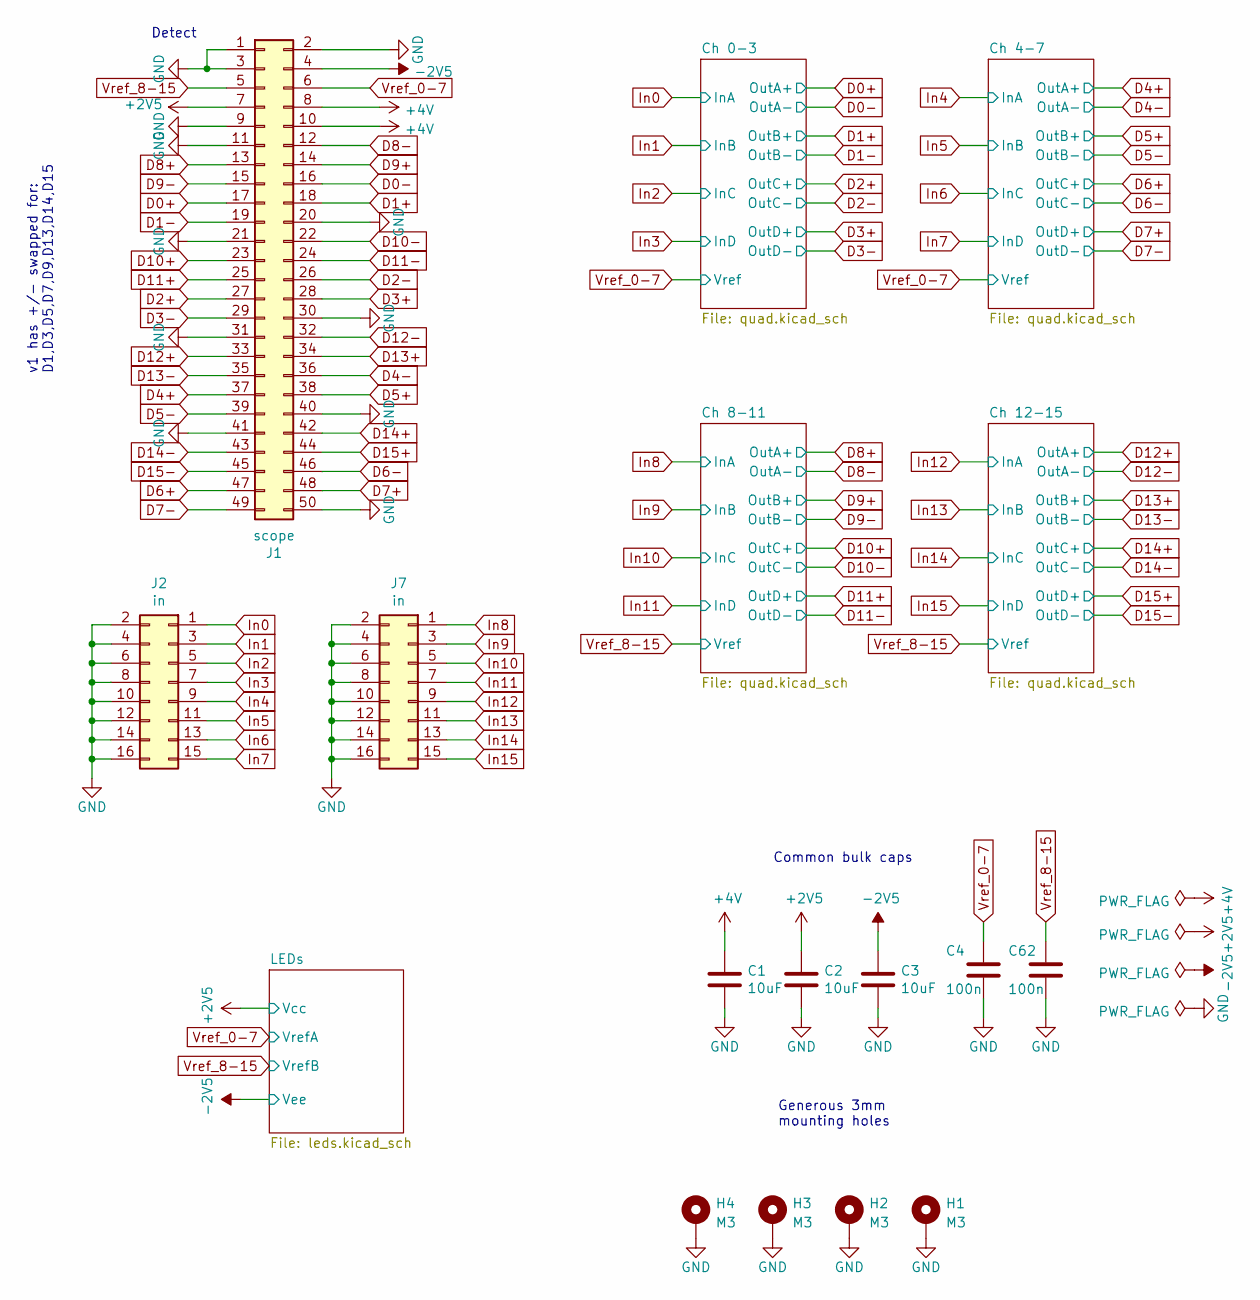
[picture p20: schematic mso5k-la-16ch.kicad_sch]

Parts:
C1, C2, C3: 10uF; C_0805_2012Metric
C4, C62: 100n; C_0603_1608Metric
H1, H2, H3, H4: M3; MountingHole_3.2mm_M3_Pad_Via
J1: scope; IDC-Header_2x25_P2.54mm_Vertical
J2, J7: in; PinSocket_2x08_P2.54mm_Vertical

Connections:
+2V5: C2.1, J1.7; also elsewhere on the board
+4V: C1.1, J1.8, J1.10; also elsewhere on the board
-2V5: C3.1, J1.4; also elsewhere on the board
D0+: J1.17; also elsewhere on the board
D0-: J1.16; also elsewhere on the board
D1+: J1.18; also elsewhere on the board
D1-: J1.19; also elsewhere on the board
D2+: J1.27; also elsewhere on the board
D2-: J1.26; also elsewhere on the board
D3+: J1.28; also elsewhere on the board
D3-: J1.29; also elsewhere on the board
D4+: J1.37; also elsewhere on the board
D4-: J1.36; also elsewhere on the board
D5+: J1.38; also elsewhere on the board
D5-: J1.39; also elsewhere on the board
D6+: J1.47; also elsewhere on the board
D6-: J1.46; also elsewhere on the board
D7+: J1.48; also elsewhere on the board
D7-: J1.49; also elsewhere on the board
D8+: J1.13; also elsewhere on the board
D8-: J1.12; also elsewhere on the board
D9+: J1.14; also elsewhere on the board
D9-: J1.15; also elsewhere on the board
D10+: J1.23; also elsewhere on the board
D10-: J1.22; also elsewhere on the board
D11+: J1.25; also elsewhere on the board
D11-: J1.24; also elsewhere on the board
D12+: J1.33; also elsewhere on the board
D12-: J1.32; also elsewhere on the board
D13+: J1.34; also elsewhere on the board
D13-: J1.35; also elsewhere on the board
D14+: J1.42; also elsewhere on the board
D14-: J1.43; also elsewhere on the board
D15+: J1.44; also elsewhere on the board
D15-: J1.45; also elsewhere on the board
GND: C1.2, C2.2, C3.2, C4.2, C62.2, H1.1, H2.1, H3.1, H4.1, J1.1, J1.2, J1.3, J1.9, J1.11, J1.20, J1.21, J1.30, J1.31, J1.40, J1.41, J1.50, J2.2, J2.4, J2.6, J2.8, J2.10, J2.12, J2.14, J2.16, J7.2, J7.4, J7.6, J7.8, J7.10, J7.12, J7.14, J7.16; also elsewhere on the board
In0: J2.1; also elsewhere on the board
In1: J2.3; also elsewhere on the board
In2: J2.5; also elsewhere on the board
In3: J2.7; also elsewhere on the board
In4: J2.9; also elsewhere on the board
In5: J2.11; also elsewhere on the board
In6: J2.13; also elsewhere on the board
In7: J2.15; also elsewhere on the board
In8: J7.1; also elsewhere on the board
In9: J7.3; also elsewhere on the board
In10: J7.5; also elsewhere on the board
In11: J7.7; also elsewhere on the board
In12: J7.9; also elsewhere on the board
In13: J7.11; also elsewhere on the board
In14: J7.13; also elsewhere on the board
In15: J7.15; also elsewhere on the board
Vref_0-7: C4.1, J1.6; also elsewhere on the board
Vref_8-15: C62.1, J1.5; also elsewhere on the board

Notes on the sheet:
Common bulk caps
v1 has +/- swapped for: D1,D3,D5,D7,D9,D13,D14,D15
Generous 3mm mounting holes
Detect

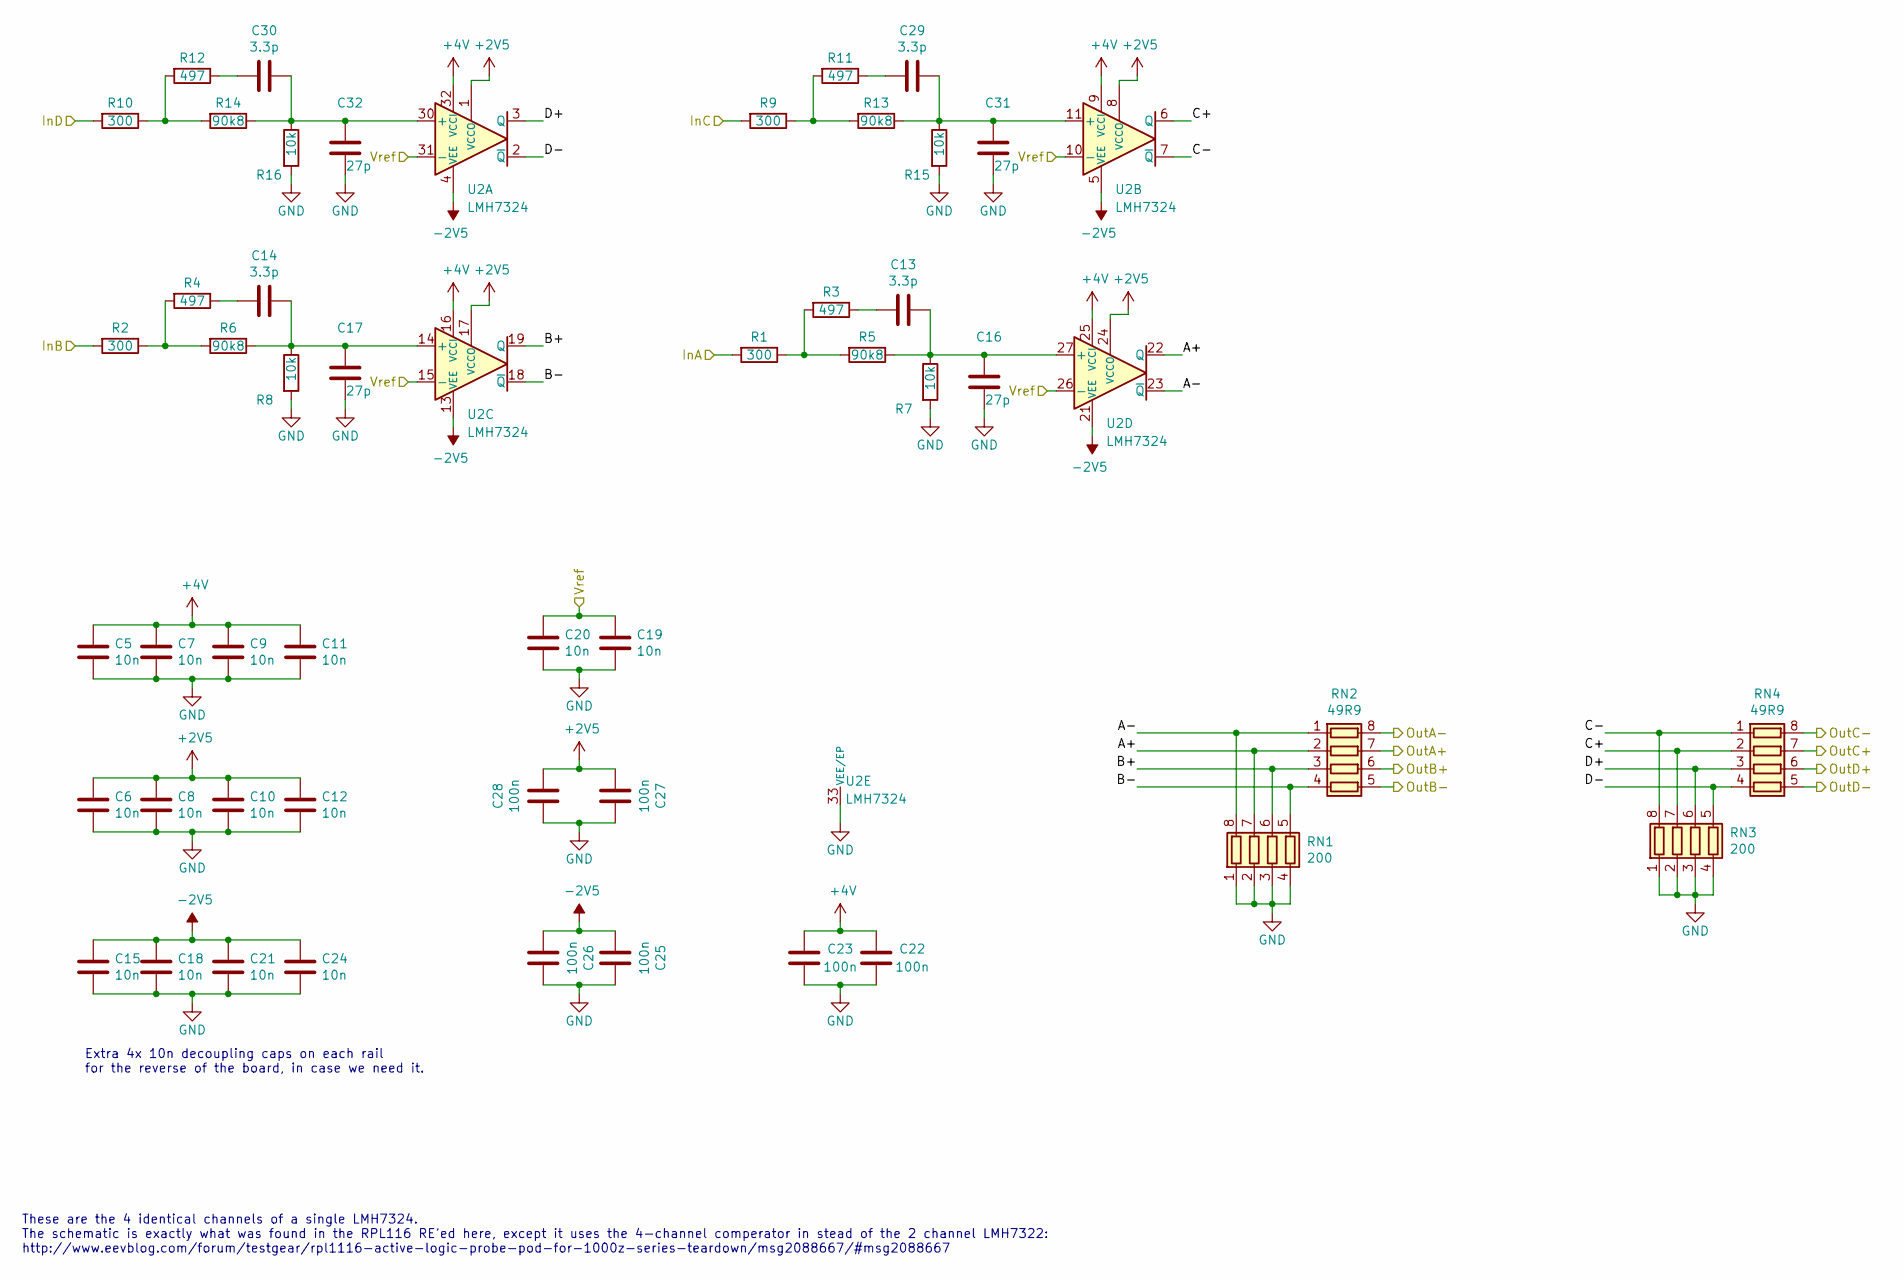
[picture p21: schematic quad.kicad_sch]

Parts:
C5, C6, C7, C8, C9, C10, C11, C12, C15, C18, C21, C24: 10n; C_0402_1005Metric
C13, C14, C29, C30: 3.3p; C_0603_1608Metric
C16, C17, C31, C32: 27p; C_0603_1608Metric
C19, C20: 10n; C_0603_1608Metric
C22, C23, C25, C26, C27, C28: 100n; C_0603_1608Metric
R1, R2, R9, R10: 300; R_0603_1608Metric
R3, R4, R11, R12: 497; R_0603_1608Metric
R5, R6, R13, R14: 90k8; R_0603_1608Metric
R7, R8, R15, R16: 10k; R_0603_1608Metric
RN1, RN3: 200; R_Array_Convex_4x0603
RN2, RN4: 49R9; R_Array_Convex_4x0603
U2: LMH7324; WQFN-32-1EP_5x5mm_P0.5mm_EP3.1x3.1mm

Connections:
+2V5: C6.1, C8.1, C10.1, C12.1, C27.2, C28.2, U2.1 (VCCO), U2.8 (VCCO), U2.17 (VCCO), U2.24 (VCCO); also elsewhere on the board
+4V: C5.1, C7.1, C9.1, C11.1, C22.1, C23.1, U2.9 (VCCI), U2.16 (VCCI), U2.25 (VCCI), U2.32 (VCCI); also elsewhere on the board
-2V5: C15.1, C18.1, C21.1, C24.1, C25.2, C26.2, U2.4 (VEE), U2.5 (VEE), U2.12 (VEE), U2.13 (VEE), U2.20 (VEE), U2.21 (VEE), U2.28 (VEE), U2.29 (VEE); also elsewhere on the board
/Ch 0-3/A+: RN1.7 (R2.2), RN2.2 (R2.1), U2.22 (Q)
/Ch 0-3/A-: RN1.8 (R1.2), RN2.1 (R1.1), U2.23 (~Q)
/Ch 0-3/B+: RN1.6 (R3.2), RN2.3 (R3.1), U2.19 (Q)
/Ch 0-3/B-: RN1.5 (R4.2), RN2.4 (R4.1), U2.18 (~Q)
/Ch 0-3/C+: RN3.7 (R2.2), RN4.2 (R2.1), U2.6 (Q)
/Ch 0-3/C-: RN3.8 (R1.2), RN4.1 (R1.1), U2.7 (~Q)
/Ch 0-3/D+: RN3.6 (R3.2), RN4.3 (R3.1), U2.3 (Q)
/Ch 0-3/D-: RN3.5 (R4.2), RN4.4 (R4.1), U2.2 (~Q)
D0+: RN2.7 (R2.2); also elsewhere on the board
D0-: RN2.8 (R1.2); also elsewhere on the board
D1+: RN2.6 (R3.2); also elsewhere on the board
D1-: RN2.5 (R4.2); also elsewhere on the board
D2+: RN4.7 (R2.2); also elsewhere on the board
D2-: RN4.8 (R1.2); also elsewhere on the board
D3+: RN4.6 (R3.2); also elsewhere on the board
D3-: RN4.5 (R4.2); also elsewhere on the board
GND: C5.2, C6.2, C7.2, C8.2, C9.2, C10.2, C11.2, C12.2, C15.2, C16.2, C17.2, C18.2, C19.2, C20.2, C21.2, C22.2, C23.2, C24.2, C25.1, C26.1, C27.1, C28.1, C31.2, C32.2, R7.2, R8.2, R15.2, R16.2, RN1.1 (R1.1), RN1.2 (R2.1), RN1.3 (R3.1), RN1.4 (R4.1), RN3.1 (R1.1), RN3.2 (R2.1), RN3.3 (R3.1), RN3.4 (R4.1), U2.33 (VEE/EP); also elsewhere on the board
In0: R1.2; also elsewhere on the board
In1: R2.2; also elsewhere on the board
In2: R9.2; also elsewhere on the board
In3: R10.2; also elsewhere on the board
unnamed: C13.2, R3.1
unnamed: C14.2, R4.1
unnamed: C29.2, R11.1
unnamed: C30.2, R12.1
unnamed: R1.1, R3.2, R5.2
unnamed: R2.1, R4.2, R6.2
unnamed: R10.1, R12.2, R14.2
unnamed: R9.1, R11.2, R13.2
unnamed: C30.1, C32.1, R14.1, R16.1, U2.30 (+)
unnamed: C29.1, C31.1, R13.1, R15.1, U2.11 (+)
unnamed: C14.1, C17.1, R6.1, R8.1, U2.14 (+)
unnamed: C13.1, C16.1, R5.1, R7.1, U2.27 (+)
Vref_0-7: C19.1, C20.1, U2.10 (-), U2.15 (-), U2.26 (-), U2.31 (-); also elsewhere on the board

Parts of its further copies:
C33, C34, C35, C36, C37, C38, C39, C40, C43, C46, C49, C52, C63, C64, C65, C66, C67, C68, C69, C70, C71, C74, C75, C76, C91, C92, C93, C94, C95, C96, C97, C98, C99, C102, C103, C104: 10n; C_0402_1005Metric
C41, C42, C57, C58, C72, C73, C87, C88, C100, C101, C115, C116: 3.3p; C_0603_1608Metric
C44, C45, C59, C60, C77, C78, C89, C90, C105, C106, C117, C118: 27p; C_0603_1608Metric
C47, C48, C79, C82, C107, C110: 10n; C_0603_1608Metric
C50, C51, C53, C54, C55, C56, C80, C81, C83, C84, C85, C86, C108, C109, C111, C112, C113, C114: 100n; C_0603_1608Metric
R17, R18, R25, R26, R38, R39, R46, R47, R54, R55, R62, R63: 300; R_0603_1608Metric
R19, R20, R27, R28, R40, R41, R48, R49, R56, R57, R64, R65: 497; R_0603_1608Metric
R21, R22, R29, R30, R42, R43, R50, R51, R58, R59, R66, R67: 90k8; R_0603_1608Metric
R23, R24, R31, R32, R44, R45, R52, R53, R60, R61, R68, R69: 10k; R_0603_1608Metric
RN5, RN7, RN9, RN11, RN13, RN15: 200; R_Array_Convex_4x0603
RN6, RN8, RN10, RN12, RN14, RN16: 49R9; R_Array_Convex_4x0603
U3, U4, U5: LMH7324; WQFN-32-1EP_5x5mm_P0.5mm_EP3.1x3.1mm

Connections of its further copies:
+2V5: C34.1, C36.1, C38.1, C40.1, C55.2, C56.2, C64.1, C67.1, C70.1, C75.1, C80.2, C83.2, C92.1, C95.1, C98.1, C103.1, C108.2, C111.2, U3.1 (VCCO), U3.8 (VCCO), U3.17 (VCCO), U3.24 (VCCO), U4.1 (VCCO), U4.8 (VCCO), U4.17 (VCCO), U4.24 (VCCO), U5.1 (VCCO), U5.8 (VCCO), U5.17 (VCCO), U5.24 (VCCO); also elsewhere on the board
+4V: C33.1, C35.1, C37.1, C39.1, C50.1, C51.1, C63.1, C66.1, C69.1, C74.1, C85.1, C86.1, C91.1, C94.1, C97.1, C102.1, C113.1, C114.1, U3.9 (VCCI), U3.16 (VCCI), U3.25 (VCCI), U3.32 (VCCI), U4.9 (VCCI), U4.16 (VCCI), U4.25 (VCCI), U4.32 (VCCI), U5.9 (VCCI), U5.16 (VCCI), U5.25 (VCCI), U5.32 (VCCI); also elsewhere on the board
-2V5: C43.1, C46.1, C49.1, C52.1, C53.2, C54.2, C65.1, C68.1, C71.1, C76.1, C81.2, C84.2, C93.1, C96.1, C99.1, C104.1, C109.2, C112.2, U3.4 (VEE), U3.5 (VEE), U3.12 (VEE), U3.13 (VEE), U3.20 (VEE), U3.21 (VEE), U3.28 (VEE), U3.29 (VEE), U4.4 (VEE), U4.5 (VEE), U4.12 (VEE), U4.13 (VEE), U4.20 (VEE), U4.21 (VEE), U4.28 (VEE), U4.29 (VEE), U5.4 (VEE), U5.5 (VEE), U5.12 (VEE), U5.13 (VEE), U5.20 (VEE), U5.21 (VEE), U5.28 (VEE), U5.29 (VEE); also elsewhere on the board
/Ch 4-7/A+: RN5.7 (R2.2), RN6.2 (R2.1), U3.22 (Q)
/Ch 4-7/A-: RN5.8 (R1.2), RN6.1 (R1.1), U3.23 (~Q)
/Ch 4-7/B+: RN5.6 (R3.2), RN6.3 (R3.1), U3.19 (Q)
/Ch 4-7/B-: RN5.5 (R4.2), RN6.4 (R4.1), U3.18 (~Q)
/Ch 4-7/C+: RN7.7 (R2.2), RN8.2 (R2.1), U3.6 (Q)
/Ch 4-7/C-: RN7.8 (R1.2), RN8.1 (R1.1), U3.7 (~Q)
/Ch 4-7/D+: RN7.6 (R3.2), RN8.3 (R3.1), U3.3 (Q)
/Ch 4-7/D-: RN7.5 (R4.2), RN8.4 (R4.1), U3.2 (~Q)
/Ch 8-11/A+: RN9.7 (R2.2), RN10.2 (R2.1), U4.22 (Q)
/Ch 8-11/A-: RN9.8 (R1.2), RN10.1 (R1.1), U4.23 (~Q)
/Ch 8-11/B+: RN9.6 (R3.2), RN10.3 (R3.1), U4.19 (Q)
/Ch 8-11/B-: RN9.5 (R4.2), RN10.4 (R4.1), U4.18 (~Q)
/Ch 8-11/C+: RN11.7 (R2.2), RN12.2 (R2.1), U4.6 (Q)
/Ch 8-11/C-: RN11.8 (R1.2), RN12.1 (R1.1), U4.7 (~Q)
/Ch 8-11/D+: RN11.6 (R3.2), RN12.3 (R3.1), U4.3 (Q)
/Ch 8-11/D-: RN11.5 (R4.2), RN12.4 (R4.1), U4.2 (~Q)
/Ch 12-15/A+: RN13.7 (R2.2), RN14.2 (R2.1), U5.22 (Q)
/Ch 12-15/A-: RN13.8 (R1.2), RN14.1 (R1.1), U5.23 (~Q)
/Ch 12-15/B+: RN13.6 (R3.2), RN14.3 (R3.1), U5.19 (Q)
/Ch 12-15/B-: RN13.5 (R4.2), RN14.4 (R4.1), U5.18 (~Q)
/Ch 12-15/C+: RN15.7 (R2.2), RN16.2 (R2.1), U5.6 (Q)
/Ch 12-15/C-: RN15.8 (R1.2), RN16.1 (R1.1), U5.7 (~Q)
/Ch 12-15/D+: RN15.6 (R3.2), RN16.3 (R3.1), U5.3 (Q)
/Ch 12-15/D-: RN15.5 (R4.2), RN16.4 (R4.1), U5.2 (~Q)
D4+: RN6.7 (R2.2); also elsewhere on the board
D4-: RN6.8 (R1.2); also elsewhere on the board
D5+: RN6.6 (R3.2); also elsewhere on the board
D5-: RN6.5 (R4.2); also elsewhere on the board
D6+: RN8.7 (R2.2); also elsewhere on the board
D6-: RN8.8 (R1.2); also elsewhere on the board
D7+: RN8.6 (R3.2); also elsewhere on the board
D7-: RN8.5 (R4.2); also elsewhere on the board
D8+: RN10.7 (R2.2); also elsewhere on the board
D8-: RN10.8 (R1.2); also elsewhere on the board
D9+: RN10.6 (R3.2); also elsewhere on the board
D9-: RN10.5 (R4.2); also elsewhere on the board
D10+: RN12.7 (R2.2); also elsewhere on the board
D10-: RN12.8 (R1.2); also elsewhere on the board
D11+: RN12.6 (R3.2); also elsewhere on the board
D11-: RN12.5 (R4.2); also elsewhere on the board
D12+: RN14.7 (R2.2); also elsewhere on the board
D12-: RN14.8 (R1.2); also elsewhere on the board
D13+: RN14.6 (R3.2); also elsewhere on the board
D13-: RN14.5 (R4.2); also elsewhere on the board
D14+: RN16.7 (R2.2); also elsewhere on the board
D14-: RN16.8 (R1.2); also elsewhere on the board
D15+: RN16.6 (R3.2); also elsewhere on the board
D15-: RN16.5 (R4.2); also elsewhere on the board
GND: C33.2, C34.2, C35.2, C36.2, C37.2, C38.2, C39.2, C40.2, C43.2, C44.2, C45.2, C46.2, C47.2, C48.2, C49.2, C50.2, C51.2, C52.2, C53.1, C54.1, C55.1, C56.1, C59.2, C60.2, C63.2, C64.2, C65.2, C66.2, C67.2, C68.2, C69.2, C70.2, C71.2, C74.2, C75.2, C76.2, C77.2, C78.2, C79.2, C80.1, C81.1, C82.2, C83.1, C84.1, C85.2, C86.2, C89.2, C90.2, C91.2, C92.2, C93.2, C94.2, C95.2, C96.2, C97.2, C98.2, C99.2, C102.2, C103.2, C104.2, C105.2, C106.2, C107.2, C108.1, C109.1, C110.2, C111.1, C112.1, C113.2, C114.2, C117.2, C118.2, R23.2, R24.2, R31.2, R32.2, R44.2, R45.2, R52.2, R53.2, R60.2, R61.2, R68.2, R69.2, RN5.1 (R1.1), RN5.2 (R2.1), RN5.3 (R3.1), RN5.4 (R4.1), RN7.1 (R1.1), RN7.2 (R2.1), RN7.3 (R3.1), RN7.4 (R4.1), RN9.1 (R1.1), RN9.2 (R2.1), RN9.3 (R3.1), RN9.4 (R4.1), RN11.1 (R1.1), RN11.2 (R2.1), RN11.3 (R3.1), RN11.4 (R4.1), RN13.1 (R1.1), RN13.2 (R2.1), RN13.3 (R3.1), RN13.4 (R4.1), RN15.1 (R1.1), RN15.2 (R2.1), RN15.3 (R3.1), RN15.4 (R4.1), U3.33 (VEE/EP), U4.33 (VEE/EP), U5.33 (VEE/EP); also elsewhere on the board
In4: R17.2; also elsewhere on the board
In5: R18.2; also elsewhere on the board
In6: R25.2; also elsewhere on the board
In7: R26.2; also elsewhere on the board
In8: R46.2; also elsewhere on the board
In9: R39.2; also elsewhere on the board
In10: R47.2; also elsewhere on the board
In11: R38.2; also elsewhere on the board
In12: R62.2; also elsewhere on the board
In13: R55.2; also elsewhere on the board
In14: R63.2; also elsewhere on the board
In15: R54.2; also elsewhere on the board
unnamed: C41.2, R19.1
unnamed: C42.2, R20.1
unnamed: C57.2, R27.1
unnamed: C58.2, R28.1
unnamed: C72.2, R40.1
unnamed: C73.2, R41.1
unnamed: C87.2, R48.1
unnamed: C88.2, R49.1
unnamed: C100.2, R56.1
unnamed: C101.2, R57.1
unnamed: C115.2, R64.1
unnamed: C116.2, R65.1
unnamed: R17.1, R19.2, R21.2
unnamed: R18.1, R20.2, R22.2
unnamed: R25.1, R27.2, R29.2
unnamed: R26.1, R28.2, R30.2
unnamed: R38.1, R40.2, R42.2
unnamed: R39.1, R41.2, R43.2
unnamed: R46.1, R48.2, R50.2
unnamed: R47.1, R49.2, R51.2
unnamed: R54.1, R56.2, R58.2
unnamed: R55.1, R57.2, R59.2
unnamed: R62.1, R64.2, R66.2
unnamed: R63.1, R65.2, R67.2
unnamed: C58.1, C60.1, R30.1, R32.1, U3.30 (+)
unnamed: C57.1, C59.1, R29.1, R31.1, U3.11 (+)
unnamed: C42.1, C45.1, R22.1, R24.1, U3.14 (+)
unnamed: C41.1, C44.1, R21.1, R23.1, U3.27 (+)
unnamed: C72.1, C77.1, R42.1, R44.1, U4.30 (+)
unnamed: C88.1, C90.1, R51.1, R53.1, U4.11 (+)
unnamed: C73.1, C78.1, R43.1, R45.1, U4.14 (+)
unnamed: C87.1, C89.1, R50.1, R52.1, U4.27 (+)
unnamed: C100.1, C105.1, R58.1, R60.1, U5.30 (+)
unnamed: C116.1, C118.1, R67.1, R69.1, U5.11 (+)
unnamed: C101.1, C106.1, R59.1, R61.1, U5.14 (+)
unnamed: C115.1, C117.1, R66.1, R68.1, U5.27 (+)
Vref_0-7: C47.1, C48.1, U3.10 (-), U3.15 (-), U3.26 (-), U3.31 (-); also elsewhere on the board
Vref_8-15: C79.1, C82.1, C107.1, C110.1, U4.10 (-), U4.15 (-), U4.26 (-), U4.31 (-), U5.10 (-), U5.15 (-), U5.26 (-), U5.31 (-); also elsewhere on the board

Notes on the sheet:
Extra 4x 10n decoupling caps on each rail for the reverse of the board, in case we need it.
These are the 4 identical channels of a single LMH7324. The schematic is exactly what was found in the RPL116 RE'ed here, except it uses the 4-channel comperator in stead of the 2 channel LMH7322: http://www.eevblog.com/forum/testgear/rpl1116-active-logic-probe-pod-for-1000z-series-teardown/msg2088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

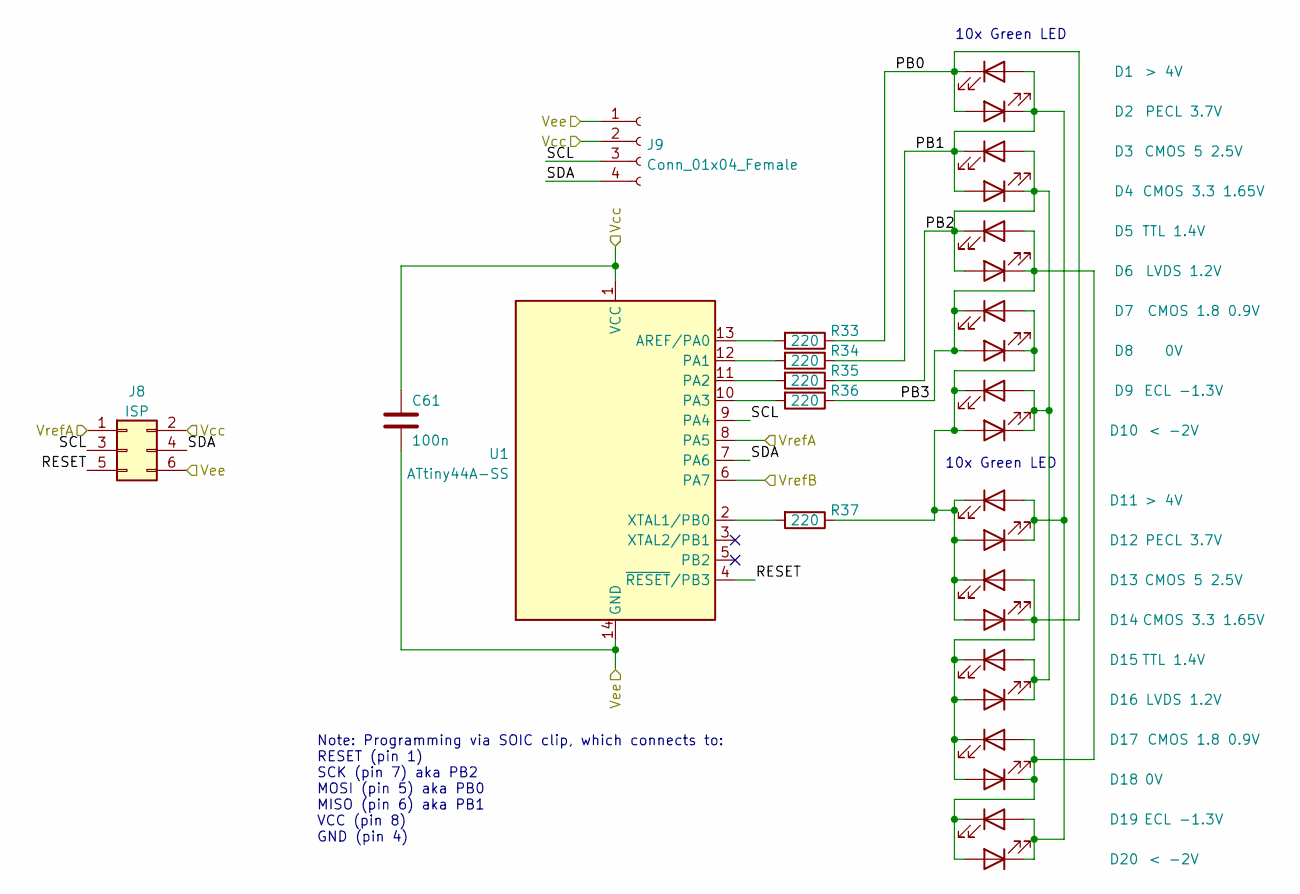
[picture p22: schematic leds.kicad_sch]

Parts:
C61: 100n; C_0603_1608Metric
D1, D11: > 4V; LED_0603_1608Metric
D2, D12: PECL 3.7V; LED_0603_1608Metric
D3, D13: CMOS 5 2.5V; LED_0603_1608Metric
D4, D14: CMOS 3.3 1.65V; LED_0603_1608Metric
D5, D15: TTL 1.4V; LED_0603_1608Metric
D6, D16: LVDS 1.2V; LED_0603_1608Metric
D7, D17: CMOS 1.8 0.9V; LED_0603_1608Metric
D8, D18: 0V; LED_0603_1608Metric
D9, D19: ECL -1.3V; LED_0603_1608Metric
D10, D20: < -2V; LED_0603_1608Metric
J8: ISP; PinHeader_2x03_P2.54mm_Vertical
J9: Conn_01x04_Female; PinHeader_1x04_P2.54mm_Vertical
R33, R34, R35, R36, R37: 220; R_0603_1608Metric
U1: ATtiny44A-SS; SOIC-14_3.9x8.7mm_P1.27mm

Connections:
+2V5: C61.1, J8.2, J9.2, U1.1 (VCC); also elsewhere on the board
-2V5: C61.2, J8.6, J9.1, U1.14 (GND); also elsewhere on the board
/LEDs/PB0: D1.1 (K), D2.2 (A), D13.2 (A), D14.1 (K), D15.1 (K), D16.2 (A), D17.1 (K), D18.2 (A), R33.1
/LEDs/PB1: D1.2 (A), D2.1 (K), D3.1 (K), D4.2 (A), D11.2 (A), D12.1 (K), D19.2 (A), D20.1 (K), R34.1
/LEDs/PB2: D3.2 (A), D4.1 (K), D5.1 (K), D6.2 (A), D9.2 (A), D10.1 (K), D15.2 (A), D16.1 (K), R35.1
/LEDs/PB3: D5.2 (A), D6.1 (K), D7.1 (K), D8.2 (A), D17.2 (A), D18.1 (K), D19.1 (K), D20.2 (A), R36.1
/LEDs/RESET: J8.5, U1.4 (~RESET/PB3)
/LEDs/SCL: J8.3, J9.3, U1.9 (PA4)
/LEDs/SDA: J8.4, J9.4, U1.7 (PA6)
unnamed: D7.2 (A), D8.1 (K), D9.1 (K), D10.2 (A), D11.1 (K), D12.2 (A), D13.1 (K), D14.2 (A), R37.1
unnamed: R33.2, U1.13 (AREF/PA0)
unnamed: R34.2, U1.12 (PA1)
unnamed: R35.2, U1.11 (PA2)
unnamed: R36.2, U1.10 (PA3)
unnamed: R37.2, U1.2 (XTAL1/PB0)
Vref_0-7: J8.1, U1.8 (PA5); also elsewhere on the board
Vref_8-15: U1.6 (PA7); also elsewhere on the board

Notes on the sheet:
Note: Programming via SOIC clip, which connects to: RESET (pin 1) SCK (pin 7) aka PB2 MOSI (pin 5) aka PB0 MISO (pin 6) aka PB1 VCC (pin 8) GND (pin 4)
10x Green LED

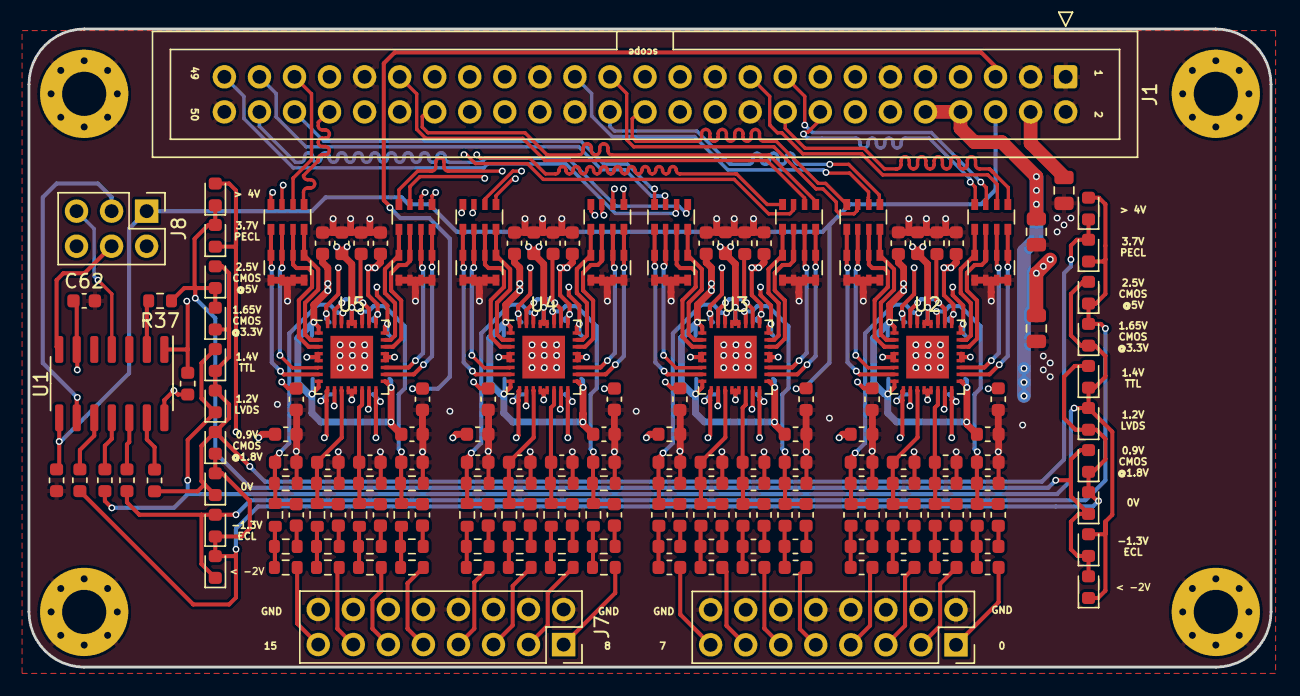
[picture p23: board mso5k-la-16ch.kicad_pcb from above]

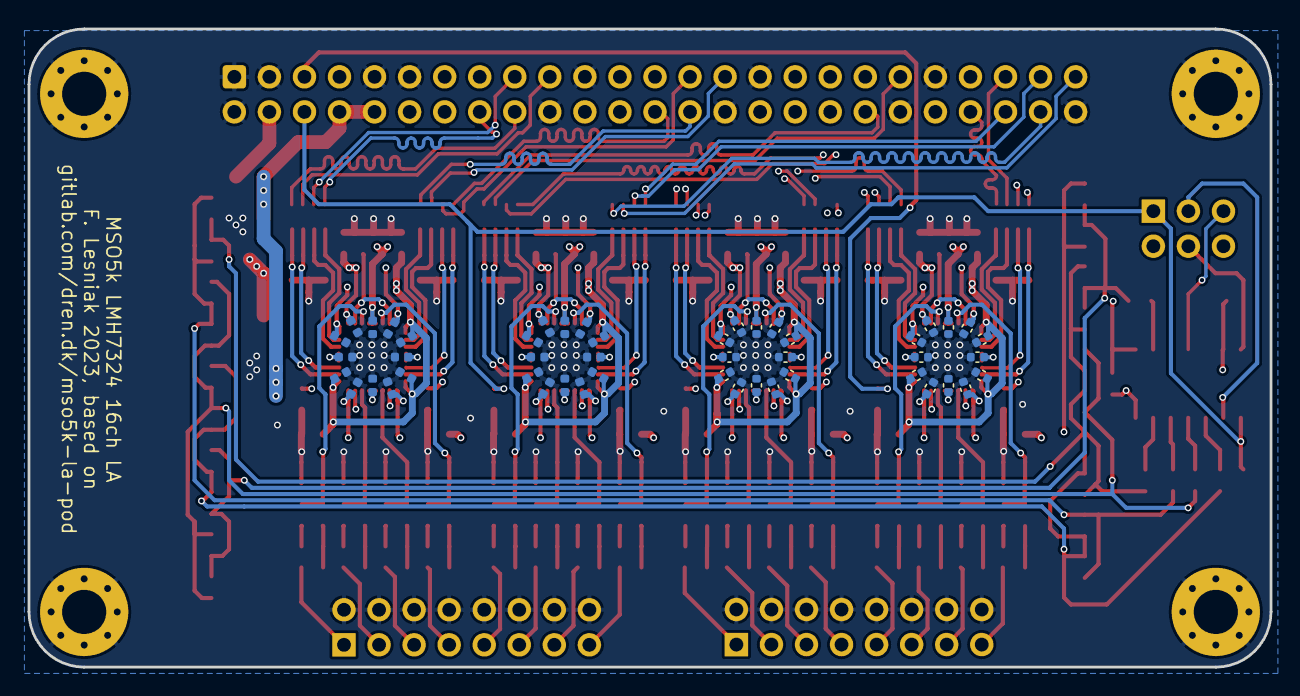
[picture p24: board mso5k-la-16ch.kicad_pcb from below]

Board: 4 copper layers, 90.0 x 46.2 mm, 236 parts (48 on the bottom side), 147 nets.

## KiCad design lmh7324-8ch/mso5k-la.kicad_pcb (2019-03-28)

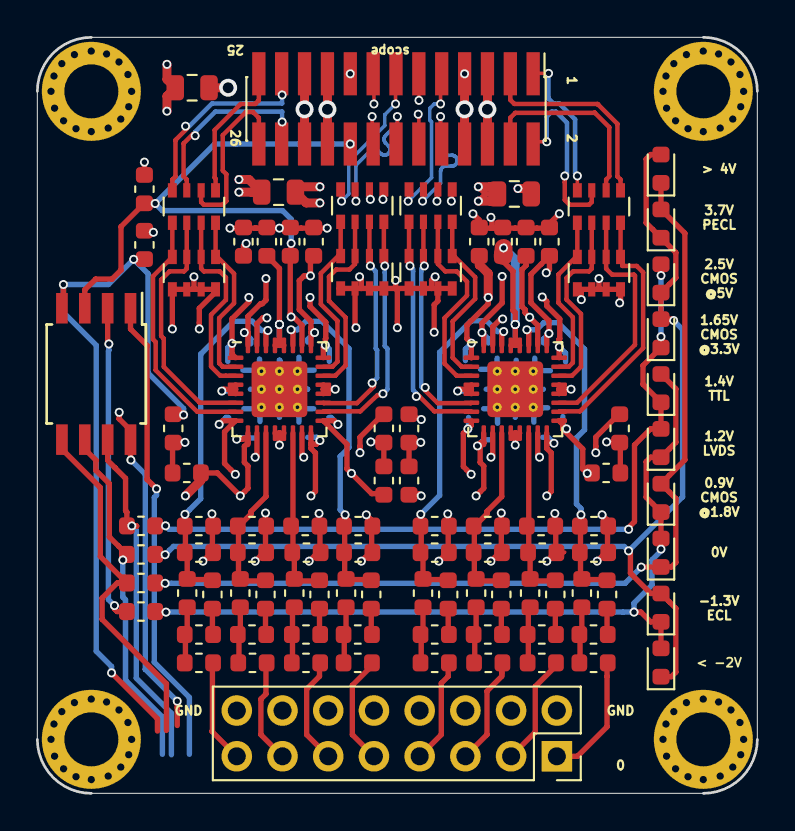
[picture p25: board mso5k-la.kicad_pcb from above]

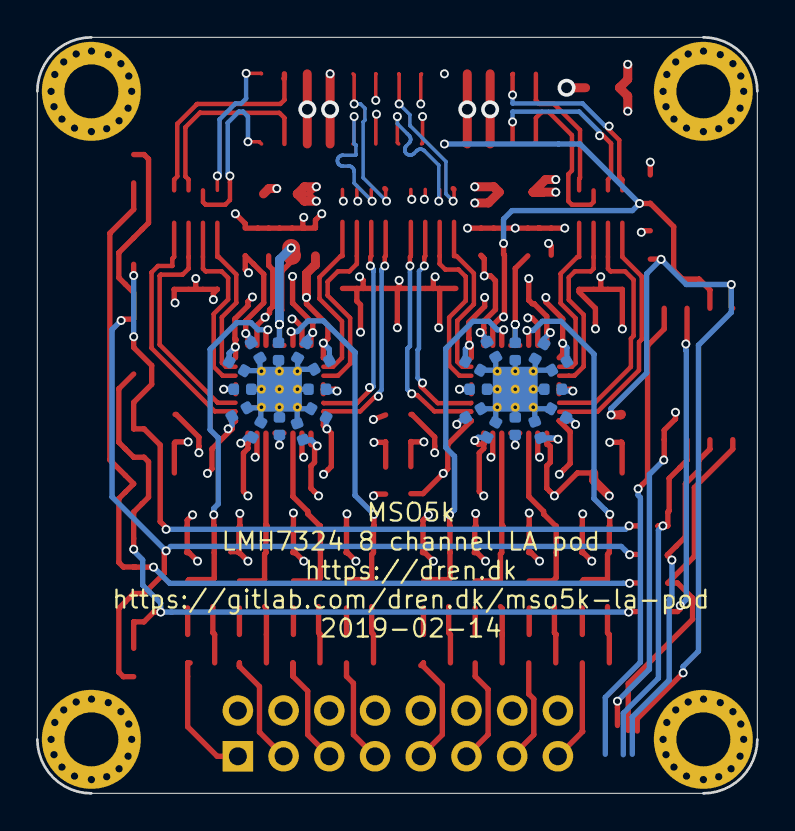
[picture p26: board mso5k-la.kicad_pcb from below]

Board: 4 copper layers, 40.0 x 42.0 mm, 124 parts (24 on the bottom side), 77 nets.

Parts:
C101, C102, C103: 10uF; C_0805_2012Metric
C104, C207, C208, C209, C210, C211, C212, C407, C408, C409, C410, C411, C412, C417: 100n; C_0603_1608Metric
C201, C202, C213, C214, C401, C402, C413, C414: 3.3p; C_0603_1608Metric
C203, C204, C215, C216, C403, C404, C415, C416: 27p; C_0603_1608Metric
C205, C206, C405, C406: 10n; C_0603_1608Metric
C217, C218, C219, C220, C221, C222, C223, C224, C225, C226, C227, C228, C301, C302, C303, C304, C305, C306, C307, C308, C309, C310, C311, C312: 10n; C_0402_1005Metric
D401: > 4V; LED_0603_1608Metric
D402: PECL 3.7V; LED_0603_1608Metric
D403: CMOS 5 2.5V; LED_0603_1608Metric
D404: CMOS 3.3 1.65V; LED_0603_1608Metric
D405: TTL 1.4V; LED_0603_1608Metric
D406: LVDS 1.2V; LED_0603_1608Metric
D407: CMOS 1.8 0.9V; LED_0603_1608Metric
D408: 0V; LED_0603_1608Metric
D409: ECL -1.3V; LED_0603_1608Metric
D410: < -2V; LED_0603_1608Metric
IC201, IC401: lmh7324; QFN-32-1EP_5x5mm_P0.5mm_EP3.1x3.1mm_ThermalVias
J101: out; PinHeader_2x13_P1.27mm_Vertical_SMD
J102: in; PinSocket_2x08_P2.54mm_Vertical
J103, J104, J105, J106: 3mm
R201, R202, R209, R210, R401, R402, R409, R410: 300; R_0603_1608Metric
R203, R204, R211, R212, R403, R404, R411, R412: 497; R_0603_1608Metric
R205, R206, R213, R214, R405, R406, R413, R414: 90k8; R_0603_1608Metric
R207, R208, R215, R216, R407, R408, R415, R416: 10k; R_0603_1608Metric
R418, R419, R420, R421: 220; R_0603_1608Metric
RN201, RN203, RN401, RN403: 200; R_Array_Convex_4x0603
RN202, RN204, RN402, RN404: 49R9; R_Array_Convex_4x0603
U401: ATtiny85-20SU; SOIJ-8_5.3x5.3mm_P1.27mm

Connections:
+2V5: C102.1, C211.2, C212.2, C218.1, C220.1, C222.1, C224.1, C302.1, C304.1, C306.1, C308.1, C411.2, C412.2, C417.1, IC201.1, IC201.8, IC201.17, IC201.24, IC401.1, IC401.8, IC401.17, IC401.24, J101.19, J101.20, U401.8
+4V: C101.1, C207.1, C208.1, C217.1, C219.1, C221.1, C223.1, C301.1, C303.1, C305.1, C307.1, C407.1, C408.1, IC201.9, IC201.16, IC201.25, IC201.32, IC401.9, IC401.16, IC401.25, IC401.32, J101.21, J101.22
-2V5: C103.1, C209.2, C210.2, C225.1, C226.1, C227.1, C228.1, C309.1, C310.1, C311.1, C312.1, C409.2, C410.2, C417.2, IC201.4, IC201.5, IC201.12, IC201.13, IC201.20, IC201.21, IC201.28, IC201.29, IC401.4, IC401.5, IC401.12, IC401.13, IC401.20, IC401.21, IC401.28, IC401.29, J101.5, J101.6, U401.4
/Ch 0-3/A+: IC401.22, RN401.7, RN402.2
/Ch 0-3/A-: IC401.23, RN401.8, RN402.1
/Ch 0-3/B+: IC401.19, RN401.6, RN402.3
/Ch 0-3/B-: IC401.18, RN401.5, RN402.4
/Ch 0-3/C+: IC401.6, RN403.7, RN404.2
/Ch 0-3/C-: IC401.7, RN403.8, RN404.1
/Ch 0-3/D+: IC401.3, RN403.6, RN404.3
/Ch 0-3/D-: IC401.2, RN403.5, RN404.4
/Ch 4-7/A+: IC201.22, RN201.7, RN202.2
/Ch 4-7/A-: IC201.23, RN201.8, RN202.1
/Ch 4-7/B+: IC201.19, RN201.6, RN202.3
/Ch 4-7/B-: IC201.18, RN201.5, RN202.4
/Ch 4-7/C+: IC201.6, RN203.7, RN204.2
/Ch 4-7/C-: IC201.7, RN203.8, RN204.1
/Ch 4-7/D+: IC201.3, RN203.6, RN204.3
/Ch 4-7/D-: IC201.2, RN203.5, RN204.4
/LEDs/PB0: D401.1, D402.2, D407.2, D408.1, R418.1
/LEDs/PB1: D401.2, D402.1, D403.1, D404.2, D409.2, D410.1, R419.1
/LEDs/PB2: D403.2, D404.1, D405.1, D406.2, R420.1
/LEDs/PB3: D405.2, D406.1, D407.1, D408.2, D409.1, D410.2, R421.1
D0+: J101.2, RN402.7
D0-: J101.1, RN402.8
D1+: J101.4, RN402.6
D1-: J101.3, RN402.5
D2+: J101.10, RN404.7
D2-: J101.9, RN404.8
D3+: J101.12, RN404.6
D3-: J101.11, RN404.5
D4+: J101.14, RN202.7
D4-: J101.13, RN202.8
D5+: J101.16, RN202.6
D5-: J101.15, RN202.5
D6+: J101.24, RN204.7
D6-: J101.23, RN204.8
D7+: J101.26, RN204.6
D7-: J101.25, RN204.5
GND: C101.2, C102.2, C103.2, C104.2, C203.2, C204.2, C205.2, C206.2, C207.2, C208.2, C209.1, C210.1, C211.1, C212.1, C215.2, C216.2, C217.2, C218.2, C219.2, C220.2, C221.2, C222.2, C223.2, C224.2, C225.2, C226.2, C227.2, C228.2, C301.2, C302.2, C303.2, C304.2, C305.2, C306.2, C307.2, C308.2, C309.2, C310.2, C311.2, C312.2, C403.2, C404.2, C405.2, C406.2, C407.2, C408.2, C409.1, C410.1, C411.1, C412.1, C415.2, C416.2, IC201.33, IC401.33, J101.7, J101.8, J101.17, J102.2, J102.4, J102.6, J102.8, J102.10, J102.12, J102.14, J102.16, J103.1, J104.1, J105.1, J106.1, R207.2, R208.2, R215.2, R216.2, R407.2, R408.2, R415.2, R416.2, RN201.1, RN201.2, RN201.3, RN201.4, RN203.1, RN203.2, RN203.3, RN203.4, RN401.1, RN401.2, RN401.3, RN401.4, RN403.1, RN403.2, RN403.3, RN403.4
In0: J102.1, R401.2
In1: J102.3, R402.2
In2: J102.5, R409.2
In3: J102.7, R410.2
In4: J102.9, R201.2
In5: J102.11, R202.2
In6: J102.13, R209.2
In7: J102.15, R210.2
unnamed: C201.1, C203.1, IC201.27, R205.1, R207.1
unnamed: C201.2, R203.1
unnamed: C202.1, C204.1, IC201.14, R206.1, R208.1
unnamed: C202.2, R204.1
unnamed: C213.1, C215.1, IC201.11, R213.1, R215.1
unnamed: C213.2, R211.1
unnamed: C214.1, C216.1, IC201.30, R214.1, R216.1
unnamed: C214.2, R212.1
unnamed: C401.1, C403.1, IC401.27, R405.1, R407.1
unnamed: C401.2, R403.1
unnamed: C402.1, C404.1, IC401.14, R406.1, R408.1
unnamed: C402.2, R404.1
unnamed: C413.1, C415.1, IC401.11, R413.1, R415.1
unnamed: C413.2, R411.1
unnamed: C414.1, C416.1, IC401.30, R414.1, R416.1
unnamed: C414.2, R412.1
unnamed: R201.1, R203.2, R205.2
unnamed: R202.1, R204.2, R206.2
unnamed: R209.1, R211.2, R213.2
unnamed: R210.1, R212.2, R214.2
unnamed: R401.1, R403.2, R405.2
unnamed: R402.1, R404.2, R406.2
unnamed: R409.1, R411.2, R413.2
unnamed: R410.1, R412.2, R414.2
unnamed: R418.2, U401.5
unnamed: R419.2, U401.6
unnamed: R420.2, U401.7
unnamed: R421.2, U401.2
Vref: C104.1, C205.1, C206.1, C405.1, C406.1, IC201.10, IC201.15, IC201.26, IC201.31, IC401.10, IC401.15, IC401.26, IC401.31, J101.18, U401.3

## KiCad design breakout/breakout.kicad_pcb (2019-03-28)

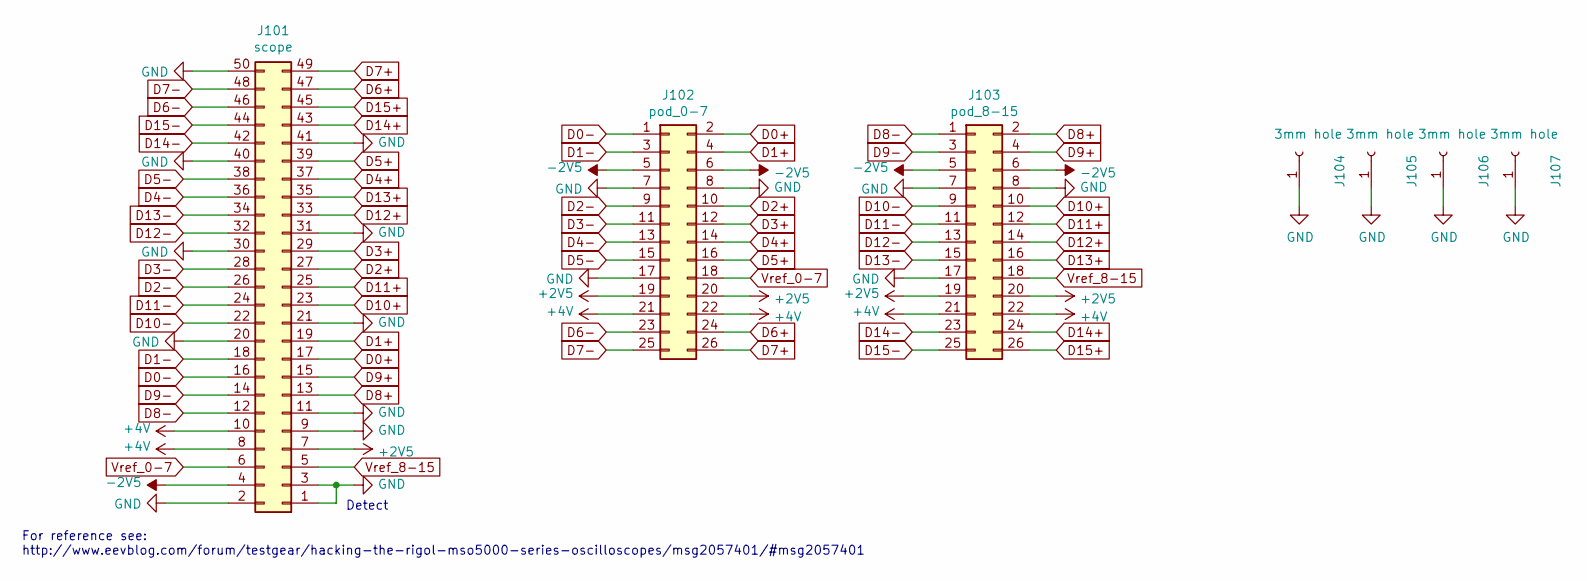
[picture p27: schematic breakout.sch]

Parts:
J101: scope; PinHeader_2x25_P2.54mm_Vertical
J102: pod_0-7; PinHeader_2x13_P1.27mm_Vertical_SMD
J103: pod_8-15; PinHeader_2x13_P1.27mm_Vertical_SMD
J104, J105, J106, J107: 3mm hole; 3mm

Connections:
+2V5: J101.7, J102.19, J102.20, J103.19, J103.20
+4V: J101.8, J101.10, J102.21, J102.22, J103.21, J103.22
-2V5: J101.4, J102.5, J102.6, J103.5, J103.6
D0+: J101.17, J102.2
D0-: J101.16, J102.1
D1+: J101.19, J102.4
D1-: J101.18, J102.3
D2+: J101.27, J102.10
D2-: J101.26, J102.9
D3+: J101.29, J102.12
D3-: J101.28, J102.11
D4+: J101.37, J102.14
D4-: J101.36, J102.13
D5+: J101.39, J102.16
D5-: J101.38, J102.15
D6+: J101.47, J102.24
D6-: J101.46, J102.23
D7+: J101.49, J102.26
D7-: J101.48, J102.25
D8+: J101.13, J103.2
D8-: J101.12, J103.1
D9+: J101.15, J103.4
D9-: J101.14, J103.3
D10+: J101.23, J103.10
D10-: J101.22, J103.9
D11+: J101.25, J103.12
D11-: J101.24, J103.11
D12+: J101.33, J103.14
D12-: J101.32, J103.13
D13+: J101.35, J103.16
D13-: J101.34, J103.15
D14+: J101.43, J103.24
D14-: J101.42, J103.23
D15+: J101.45, J103.26
D15-: J101.44, J103.25
GND: J101.1, J101.2, J101.3, J101.9, J101.11, J101.20, J101.21, J101.30, J101.31, J101.40, J101.41, J101.50, J102.7, J102.8, J102.17, J103.7, J103.8, J103.17, J104.1, J105.1, J106.1, J107.1
Vref_0-7: J101.6, J102.18
Vref_8-15: J101.5, J103.18

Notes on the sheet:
For reference see: http://www.eevblog.com/forum/testgear/hacking-the-rigol-mso5000-series-oscilloscopes/msg2057401/#msg2057401
Detect

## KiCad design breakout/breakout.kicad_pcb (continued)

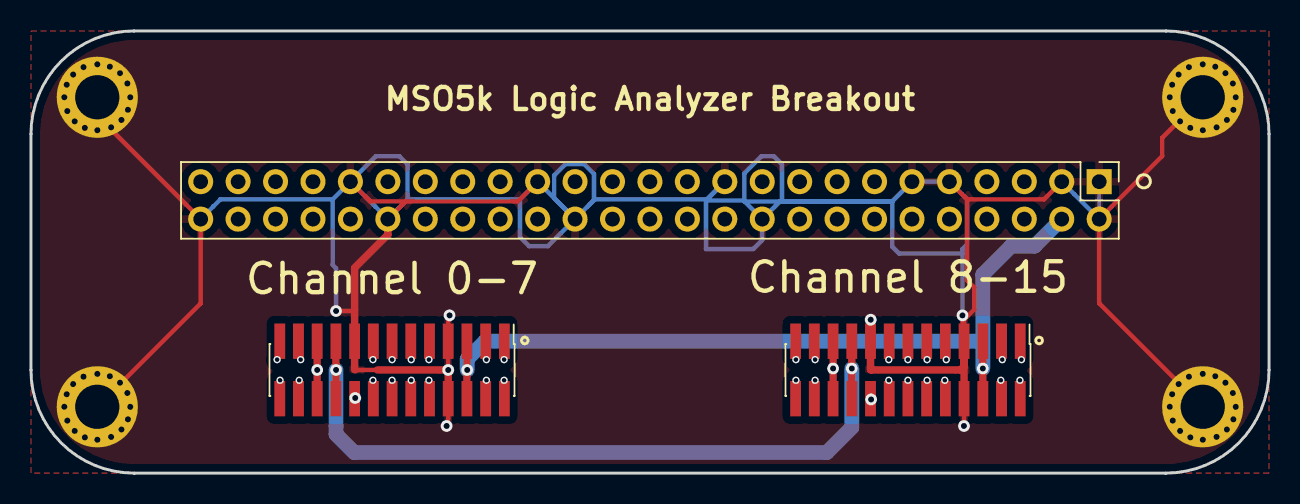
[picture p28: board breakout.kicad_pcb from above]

Board: 4 copper layers, 84.0 x 30.0 mm, 7 parts (0 on the bottom side), 38 nets.

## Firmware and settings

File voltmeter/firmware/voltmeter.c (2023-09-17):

#include <stdbool.h>
#include <stdio.h>
#include <stdlib.h>
#include <avr/interrupt.h>
#include <avr/power.h>
#include <avr/sleep.h>
#include <avr/wdt.h>
#include <util/delay.h>

#include "adc.h"
#include "board.h"
#include "calibration.h"
#include "charlie.h"

static Calibration calibration;
static enum { calNone, calHigh, calLow, calDone } calState = calNone;

// called at ~4Hz
ISR(TIM1_COMPA_vect) {
  static uint8_t currentChannel = 0;

  if (calState == calNone) {
    currentChannel++;
    if (currentChannel >= ADC_CHANNELS) {
      currentChannel = 0;
    }

    const uint16_t adc = getADC(currentChannel);
    const uint16_t mv = adcToMiliVolt(&calibration, adc);
    const LedPoint* lp = voltageToLeds(currentChannel, mv);
    setCharlieLedPoint(currentChannel, lp);
  } else {
    setCharlieLedOff(1);
  }
}

// enter calibration mode by jumpering PA6 to -2.5V / AVR GND
bool getCalMode() {
  return GPREAD(CALIB) == 0;
}

int main(void) {
  wdt_enable(WDTO_1S);
  // clock_prescale_set(clock_div_8);

  // charlie led driver overwrites DDR, configure pins there!
  // GPINPUT(VREF0);
  // GPINPUT(VREF1);
  // GPINPUT(CALIB);

  // setup the utility Timer/Counter1 to ~4Hz
  TCCR1B = _BV(WGM12) | _BV(CS12); // prescaler /256, clear timer on compare
  OCR1A = F_CPU / 256 / 4; // 4Hz ~= 7812 @ 8MHz
  TIMSK1 |= _BV(TOIE1) | _BV(OCIE1A); // Generate interrupts at overflow and A

  initCharlieLeds();
  startADC(); // Starts the ADC interrupt in free-running mode
  readCalibrationOrSetDefault(&calibration);

  uint8_t calAdcCount = 0;
  uint16_t calAdcLow = 0, calAdcHigh = 0;

  sei();
  while (1) {
    wdt_reset();

    uint16_t calAdcTemp;
    switch (calState) {
      case calLow:
        if (calAdcCount == 4) {
          setCharlieLed(0,8); // -1.3V
          calAdcCount = 0;
          calAdcTemp = getADC(0);
          if (!getCalMode())
            calState = calDone;
          else if (calAdcTemp >= 550 << ADC_OVERSAMPLES_SHIFT)
            calState = calHigh;
          else
            calAdcLow = calAdcTemp;
        } else {
          setCharlieLedOff(0);
          calAdcCount++;
        }

        _delay_ms(200);
        break;
      case calHigh:
        if (calAdcCount == 4) {
          setCharlieLed(0,1); // 3.7V
          calAdcCount = 0;
          calAdcTemp = getADC(0);
          if (!getCalMode())
            calState = calDone;
          else if (calAdcTemp < 550 << ADC_OVERSAMPLES_SHIFT)
            calState = calLow;
          else
            calAdcHigh = calAdcTemp;
        } else {
          setCharlieLedOff(0);
          calAdcCount++;
        }

        _delay_ms(200);
        break;
      case calDone:
        if (calAdcCount == 8) {
          setCharlieLedOff(0);
          storeCalibrationFromReferenceVoltages(&calibration,
            calAdcLow, -130,
            calAdcHigh, 370);
          calState = calNone;
          calAdcCount = 0;
        } else {
          if (calAdcCount % 2)
            setCharlieLed(0,8); // -1.3V
          else
            setCharlieLed(0,1); // 3.7V
          calAdcCount++;
        }

        _delay_ms(200);
        break;
      default:
        if (getCalMode())
          calState = calLow;
        else
          calState = calNone;
        sleep_cpu();
    }
  }
}

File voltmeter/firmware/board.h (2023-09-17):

#pragma once

#include "avr8gpio.h"

/*
| Define         | AVR | Pin | Description |
|----------------|-----|-----|-------------|
| LED0           | PA0 | 13  | LED0        |
| LED1           | PA1 | 12  | LED1        |
| LED2           | PA2 | 11  | LED2        |
| LED3           | PA3 | 10  | LED3        |
| LED4           | PB0 | 2   | LED3        |
| CALIB          | PA6 | 7   | Calibration |
| VREF0          | PA5 | 8   | VrefA       |
| VREF1          | PA7 | 6   | VrefB       |
|                | PB3 | 4   | Reset       |
*/

#define LED0  GPA0
#define LED1  GPA1
#define LED2  GPA2
#define LED3  GPA3
#define LED4  GPB0
#define CALIB GPA6

#define VREF0 GPA5
#define VREF1 GPA7
#define VREF0_ADC 5
#define VREF1_ADC 7

//#define SOFTWARE_TX GPB0

// pullup for calibration input
#define DEFAULT_PORTA (_BV(PA6))

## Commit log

2019-01-17 Use resistor arrays in the outputs
    [dual.sch]
2019-01-17 Minor cleanup
    [dual.sch, mso5k-la.sch]
2019-01-18 Started playing around with the PCB layout
    [dual.sch, mso5k-la.sch]
2019-01-21 Finished the 4-layer single-sided board
    [dual.sch, foo.mso5k-la.kicad_pcb, mso5k-la.kicad_pcb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]
2019-01-24 Trying mass-edit of net names
    [mso5k-la.kicad_pcb, mso5k-la.sch, quad.sch]
2019-01-26 completed core layout of 16 channel lmh7324 design
    [mso5k-la.kicad_pcb, mso5k-la.sch, quad.sch]
2019-01-26 Forgot to add the 8 ch lmh7322 version
    [backup-2019-01-23-21-01-26-mso5k-la.kicad_pcb, backup-2019-01-24-19-01-16-mso5k-la.kicad_pcb, backup-2019-01-24-19-01-44-mso5k-la.kicad_pcb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]
2019-01-26 Laid out the 8ch LMH7324 version and added a threshold display too
    [backup-2019-01-25-20-01-09-mso5k-la.kicad_pcb, backup-2019-01-25-20-01-16-mso5k-la.kicad_pcb, backup-2019-01-25-20-01-43-mso5k-la.kicad_pcb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]
2019-01-26 Completed lmh7324 based 8ch pod with voltmeter
    [mso5k-la.kicad_pcb]
2019-01-26 Added the schematic of the 8ch lmh7324 based pod
2019-01-28 Golden revision before switching to SMD 1.27mm pitch header
    [mso5k-la.kicad_pcb]
2019-01-28 Switched to an SMD 1.27 mm pitch header for the cable to the scope to get a thinner uplink ribbon
    [backup-2019-01-25-20-01-09-mso5k-la.kicad_pcb, backup-2019-01-25-20-01-16-mso5k-la.kicad_pcb, backup-2019-01-25-20-01-43-mso5k-la.kicad_pcb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]
2019-01-29 Added breakout
    [breakout.kicad_pcb, breakout.sch, mso5k-la.kicad_pcb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]
2019-01-30 Laid out 4 layer breakout board
    [breakout.kicad_pcb, breakout.sch]
2019-01-30 Switched to 0805 on the pod for the large bulk caps
    [breakout.kicad_pcb, mso5k-la.kicad_pcb, mso5k-la.sch]
2019-03-05 Added proper readme
    [breakout.kicad_pcb, fucked-mso5k-la.kicad_pcb, mso5k-la.kicad_pcb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]
2019-03-19 Added fixes for E1 and E2
    [leds.sch, mso5k-la.kicad_pcb]
2019-03-28 Cleaning up
    [backup-2019-01-23-21-01-26-mso5k-la.kicad_pcb, backup-2019-01-24-19-01-16-mso5k-la.kicad_pcb, backup-2019-01-24-19-01-44-mso5k-la.kicad_pcb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]
2019-03-28 Started work on the volt meter code with a software uart to allow reading out the adc values, calling the adc causes everything to hang, though
2019-03-30 Moved the ADC reading code to a free-running IRQ and bumped the clock frequency to 8 MHz to get better baud rate out of the software uart, might need to go back to 1MHz later
2019-03-31 Moved to interrupt driven ADC and charlieplexing
2019-04-07 Fixed LED voltages and calibration code
    [board.h, calibration.c, charlie.c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]
2019-04-12 Fixed startup animation so all LEDs are lit
    [voltmeter.c]
2023-08-23 initial voltmeter for 16ch version
2023-09-17 firmware: final version with calibration for 16ch version
2023-09-17 lmh7324-16ch version schematics + board
    [leds.kicad_sch, mso5k-la-16ch.csv, mso5k-la-16ch.kicad_pcb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]
